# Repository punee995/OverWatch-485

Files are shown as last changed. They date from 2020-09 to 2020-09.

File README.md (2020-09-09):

# OverWatch-485!

Project **OverWatch** initially created for GUVNL R&D Department to Monitor Modbus 3-phase meters over LoRaWAN (IN865). Hardware is developed under KiCAD5. Firmware was written under CoIDE.

## Hardware Specification

 - [x] Universal Input Voltage ( 85VAC - 265VAC )
 - [x] Input surge Voltage protection ( 2000V )
 - [x] Modbus Galvenic Isolation ( 2500V )
 - [x] U.fl Antenna / SMA Antenna / PCB Antenna ( 3dbi* )
 - [x] Protocol : RS422 / RS485 ( 500kbps )
 - [x] Internal Battery / Charger
 - [ ] Reduced Power Consumption

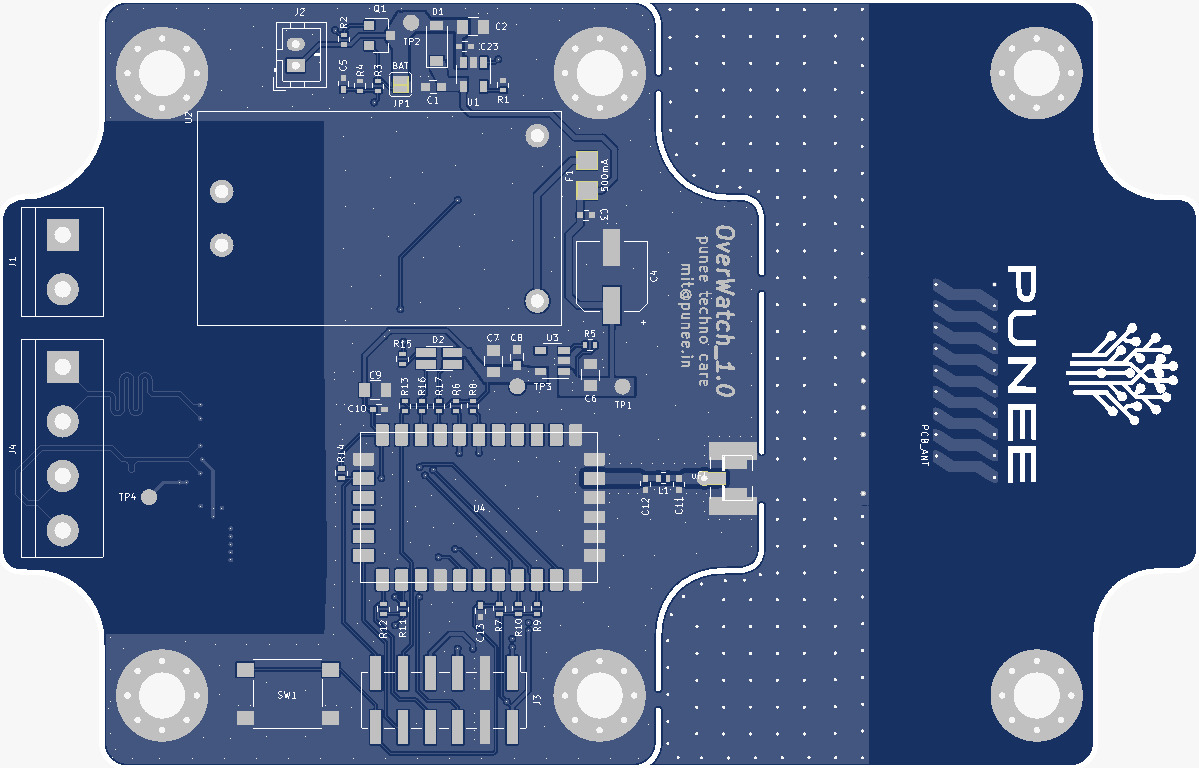
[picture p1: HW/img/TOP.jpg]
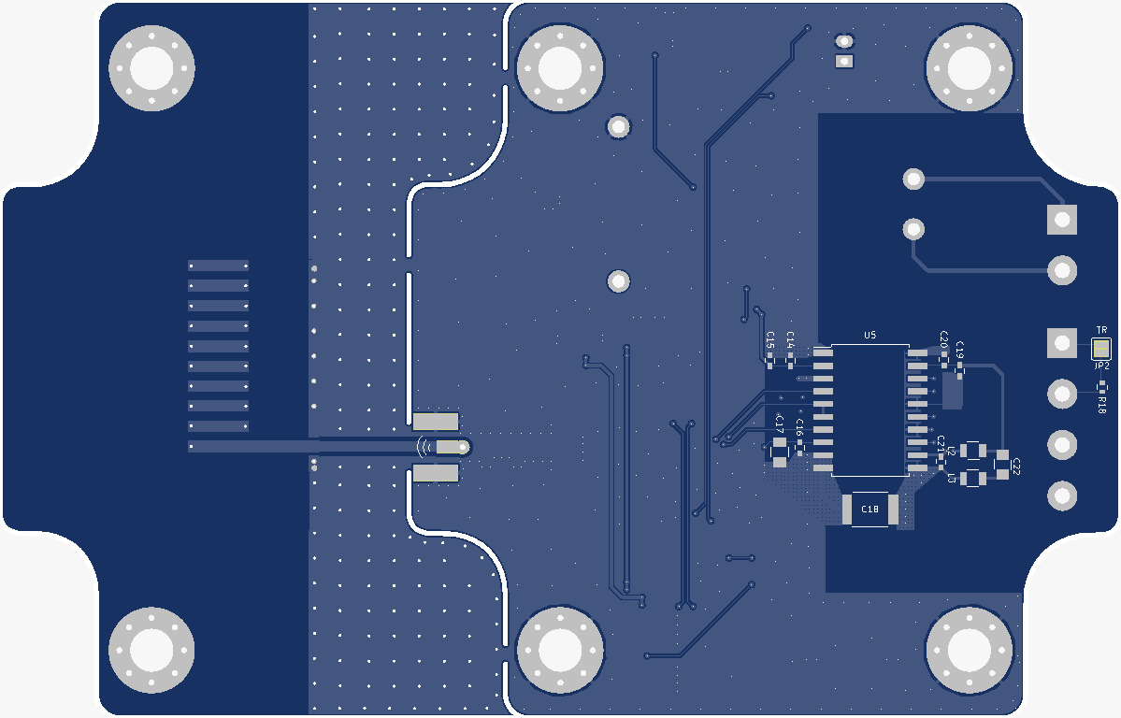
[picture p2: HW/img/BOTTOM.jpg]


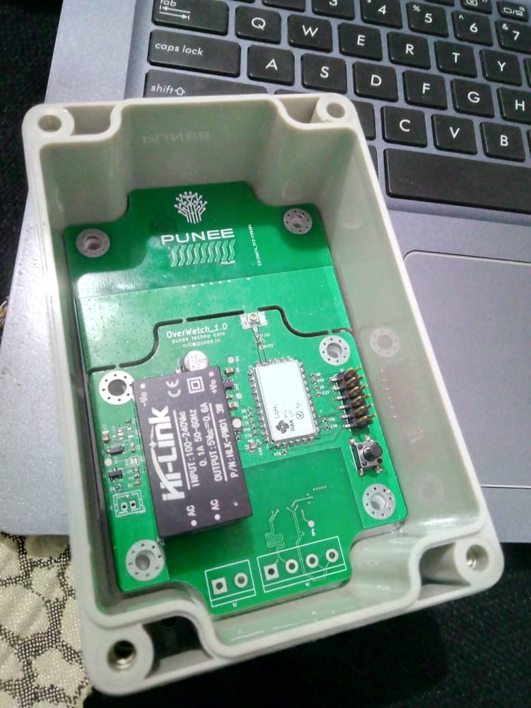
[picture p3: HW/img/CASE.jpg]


## Software Specification
1.  Add the AT command, the command list is shown below;
2.  Modify the time of sending data, and modify it to send a packet of data for 60s;
3.  Integrate all frequency bands, support band switching, and switch frequency bands by AT command;

     AT command list: \
     at+region=EU868/US915/AS923/AU915/IN865/KR920    // Set device region
     
     at+dev_eui=xxxxxxxxxxxxxxxx                      //  Set device dev_eui  \
     at+app_eui=xxxxxxxxxxxxxxxx                      // Set device app_eui  \
     at+app_key=xxxxxxxxxxxxxxxxxxxxxxxxxxxxxxxx      //  Set device app_key 

     at+dev_addr=xxxxxxxx                             // Set device dev_addr \
     at+nwks_key=xxxxxxxxxxxxxxxxxxxxxxxxxxxxxxxx     //  Set device nwks_key  \
     at+apps_key=xxxxxxxxxxxxxxxxxxxxxxxxxxxxxxxx     // Set device apps_key  

     at+join_mode=otaa/abp                            // Set the device to join otaa or abp \

     (Note:Please set the region first, then set the join method.)  \
     After the parameter setting is completed, reset the device enable parameter.

# TODO

## Hardware

 - [ ] Reduce Power Consumption (Currently ~45mA ).
	 - For this Add mosfet to Modbus transreciver.
 - [ ] Add Switch for Device Function as Maseter/Slave.
 - [ ] Protection Devices such as MOV and Fuse(@Mains side).

## Software 

 - [ ] programming of Device over RS485(Modbus).
	 - Settings of LoRaWAN Parameters.
	 - Settings of Modbus Registers.
	 - Settings of Alarm for Alert.

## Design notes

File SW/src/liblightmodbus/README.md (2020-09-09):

# A lightweight, cross-platform Modbus library




<br>[Liblightmodbus on launchpad...](https://launchpad.net/liblightmodbus)

`liblightmodbus` is a very lightweight, highly configurable, platform-independent Modbus RTU library.

## Features
- Minimal resources usage
- Relatively easy to use
- Supports all basic Modbus functions and allows users to define thier own Modbus function handlers
- You can pick specific modules, you want to be included during customized build process
- Supports register/coil access callback functions

*Currently supported functions include: 01, 02, 03, 04, 05, 06, 15, 16 and 22.*
Check out the [online documentation](https://jacajack.github.io/liblightmodbus/) for more technical information and user guide.

If you need help - [email me](mailto:mrjjot@gmail.com). If you want to help - contribute here, on Github. **All contributions are welcome!**

## Platforms on which liblightmodbus is known to run
 - 8-bit AVR (ATmega 8, ATmega 328, etc.)
 - STM32 ARM (STM32F103, STM32L151, etc.)
 - Raspberry Pi
 - i386, amd64
 - PowerPC

## PPA
On Ubuntu/Debian `liblightmodbus` can be obtained from [PPA](https://code.launchpad.net/~mrjjot/+archive/ubuntu/liblightmodbus) (Personal Package Archive).

This is how to install it:
 - Add PPA to your system - `sudo add-apt-repository ppa:mrjjot/liblightmodbus`
 - Update software lists - `sudo apt-get update`
 - Install development package - `sudo apt-get install liblightmodbus-dev`

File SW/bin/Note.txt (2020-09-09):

------------------------------------------------------
*****************************************************
------------------------------------------------------
软件版本V1.1.3 / Software version V1.1.3
更新记录： / Update record:
1.添加支持AT命令，命令列表下表所示； / 1. Add the AT command, the command list is shown below;
2.修改发送数据时间，修改为60s发送一包数据； / 2. Modify the time of sending data, and modify it to send a packet of data for 60s;
3.整合所有频段，支持频段切换，通过AT命令切换频段。 / 3. Integrate all frequency bands, support band switching, and switch frequency bands by AT command;

AT命令列表: / AT command list:

at+region=EU868/US915/AS923/AU915/IN865/KR920    // 设置设备地区频段 / Set device region

at+dev_eui=xxxxxxxxxxxxxxxx                      // 设置设备dev_eui / Set device dev_eui
at+app_eui=xxxxxxxxxxxxxxxx                      // 设置设备app_eui / Set device app_eui
at+app_key=xxxxxxxxxxxxxxxxxxxxxxxxxxxxxxxx      // 设置设备app_key / Set device app_key

at+dev_addr=xxxxxxxx                             // 设置设备dev_addr / Set device dev_addr
at+nwks_key=xxxxxxxxxxxxxxxxxxxxxxxxxxxxxxxx     // 设置设备nwks_key / Set device nwks_key
at+apps_key=xxxxxxxxxxxxxxxxxxxxxxxxxxxxxxxx     // 设置设备apps_key / Set device apps_key

at+join_mode=otaa/abp                            // 设置设备加入方式 otaa 或者 abp / Set the device to join otaa or abp

(Note:Please set the region first, then set the join method.)
参数设置完成后，复位设备启用参数。 / After the parameter setting is completed, reset the device enable parameter.

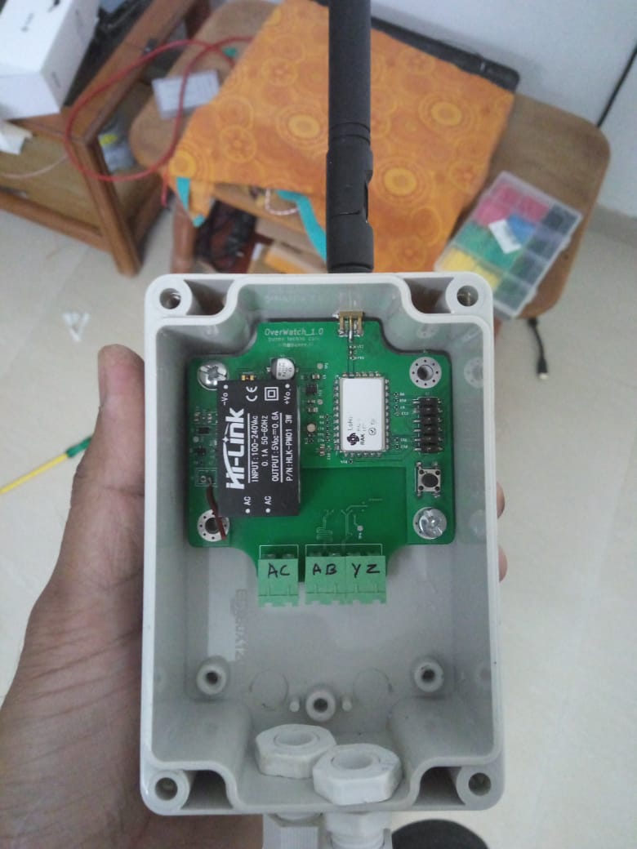
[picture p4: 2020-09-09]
HW/img/EXT_ANT.jpg

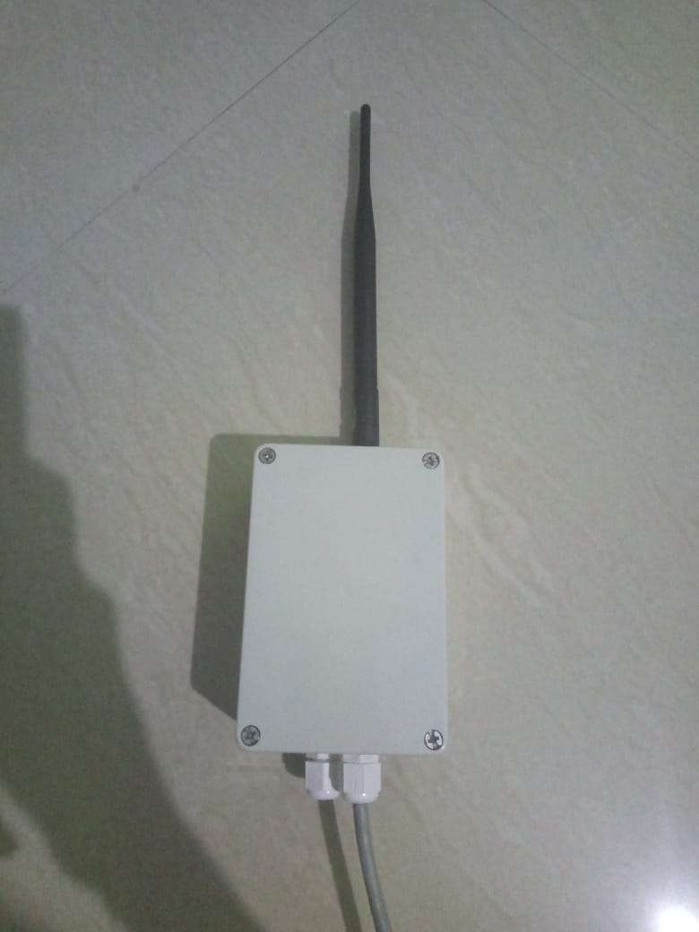
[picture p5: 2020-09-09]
HW/img/index3.jpg

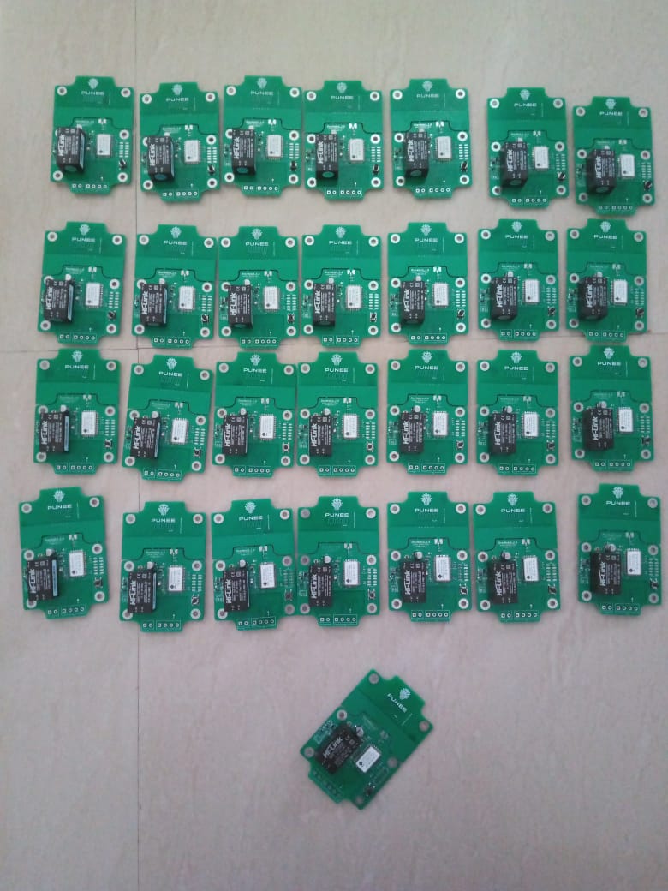
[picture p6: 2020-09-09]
HW/img/FIRST30.jpg

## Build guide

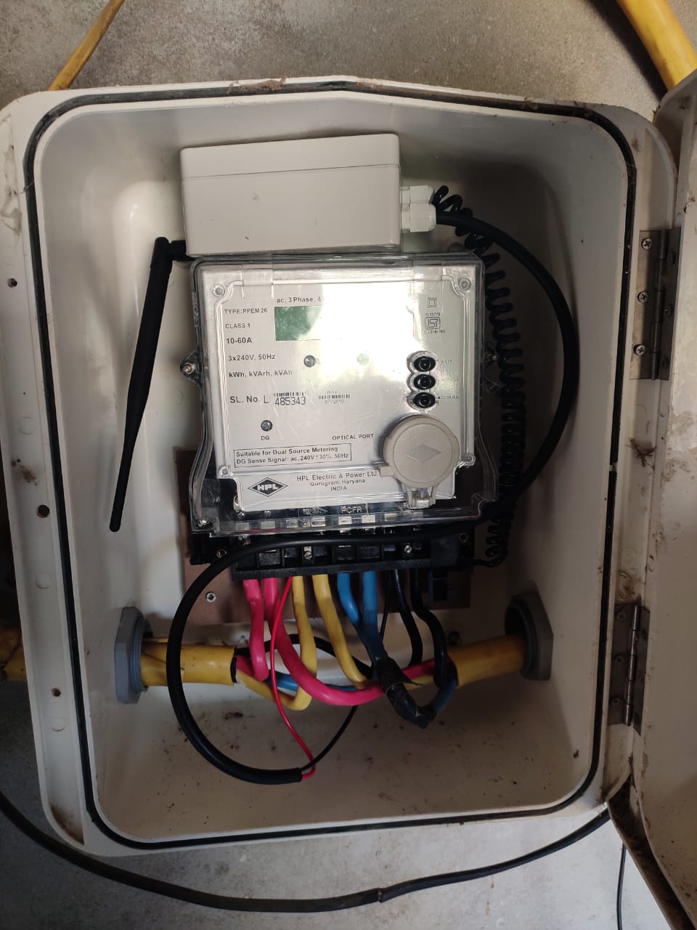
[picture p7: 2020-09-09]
HW/img/INSTALLATION.jpg

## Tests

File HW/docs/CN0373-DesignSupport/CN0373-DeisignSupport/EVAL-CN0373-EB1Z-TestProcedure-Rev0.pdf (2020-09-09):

## CN-0167/CN-0373 Evaluation Board Test Procedure

TEST SET-UP AND EQUIPMENT
Table 1 contains a list of equipment required for this test procedure. Set up and connect the equipment as directed and shown in Figure 1. All connection points and jumper location names refer to the labels on the CN-0167/CN-0373 evaluation board.
Description | Quantity
Adjustable Power Supply (+6 V) | 1
Oscilloscope and 3 probes | 1
Multimeter | 1
Laptop with Tera Term Emulator | 1
USB cable | 1

Procedure:
1. Apply 6 V to the J1 Barrel socket connector to power the board.
2. Connect a USB cable from the Laptop/PC to the J4 connector
3. Install the Tera Term Emulator on the PC/Laptop if required
4. Open a Tera Term emulator window.
a. Select COM5 for RS-232 transmission. Set the Tera Term Serial Port baud rate to 460800.
b. Select COM6 for RS-485 transmission. Set the Tera Term Serial Port baud rate to 460800.
5. Connect the oscilloscope probes to the ISOTXD, Y, and Z test points.

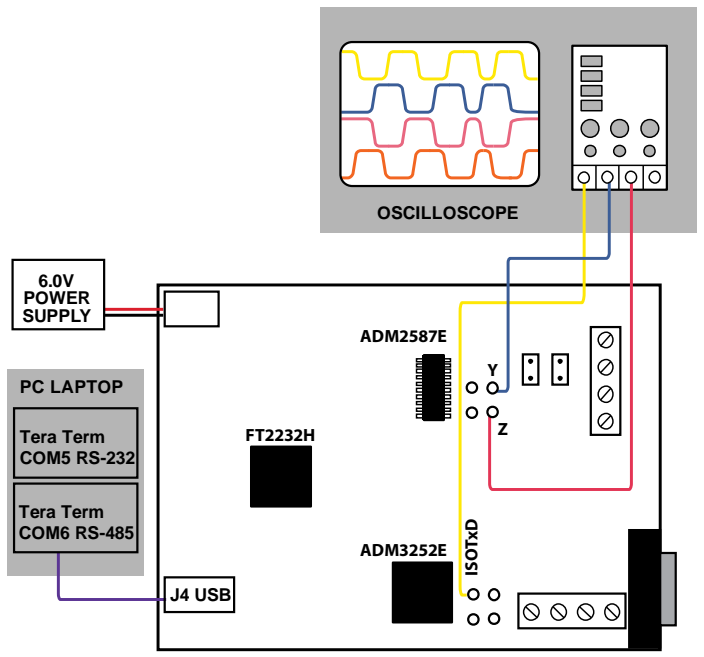
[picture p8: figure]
OSCILLOSCOPE; 6.0V POWER SUPPLY; Tera Term COM6 RS-485; J4 USB; ADM2587E; ADM3252E; OTxD; Z Tera Term COM5 RS-232; PC LAPTOP

Figure 1, Test Setup and Equipment

## CN-0167/CN-0373 Evaluation Board Test Procedure

TEST PROCEDURE

Ensure that setup steps 1 – 5 have been completed. Then perform the initial voltage checks on the test points listed.

INITIAL VOLTAGE CHECK
Measurement Description | Test Point(s) | Typical | Upper Limit | Lower Limit
Measure Input Voltage to the board with the multimeter between barrel connector C1 capacitor and GND1 | C1 capacitor and GND1 | 6.0 V
Measure Input Voltage to the board with the multimeter between U6 pin1 and GND1 | U6 pin1 and GND1 | 5.0 V
Measure voltage on the board with the multimeter between: VCC_REG and GND1_1 | VCC_REG and GND1_1 | 4.99 V
Measure voltage on the board with the multimeter between: ISO_VCC and GND1 | ISO_VCC and GND1 | 3.3 V
Measure voltage on the board with the multimeter between: +1_8V and GND1 | +1_8V and GND1 | 1.8 V
Measure voltage on the board with the multimeter between: VCC and GND3 | VCC and GND3 | 3.3 V
Measure voltage on the board with the multimeter between: LK1 position A ,and GND3 | LK1 position A, and GND3 | 3.3 V
Measure voltage on the board with the multimeter between: VCC1 and GND | VCC1 and GND | 3.3 V
Measure voltage on the board with the multimeter between: VISO and ISOGND | VISO and ISOGND | 3.35 V
Measure voltage on the board with the multimeter between: VISO1 and GND4 | VISO1 and GND4 | 3.34 V

TRANSMIT FROM USB PORT TO RS-485/RS-232 PORTS SIMULTANEOUSLY
1. Connect a USB cable from the Laptop/PC to the J4 connector.
2. Attach an oscilloscope probe to the ISOTXD test point next to the ADM3252E transceiver as shown in Figure 1.
a. Ensure that ISOGND is used as the ground connection for the oscilloscope probe.
3. Attach an oscilloscope probe to the Y and Z test points next to the ADM2587E transceiver as shown in Figure 1.
a. Ensure that Jumpers LK5 and LK6 are not connected. Ensure that Jumper LK1 is connected in position A.
b. Ensure that GND4 is used as the ground connection for the oscilloscope probes.
c. Use the MATH function of the oscilloscope to show the Y-Z differential signal.
4. Open a Tera Term emulator window, and select COM5 for RS-232 transmission, as shown in Figure 1. Set the Tera Term Serial Port baud rate to 460800. [Data: 8 bit, Parity: none, Stop: 1 Bit, Flow Control: none]
5. Open a Tera Term emulator window, and select COM6 for RS-485 transmission, as shown in Figure 1. Set the Tera Term Serial Port baud rate to 460800. [Data: 8 bit, Parity: none, Stop: 1 Bit, Flow Control: none]
6. Load the RS-485 and RS-232 data to be transmitted by selecting the Send option under the File menu for both COM5 and COM6. Choose any large data size file for continuous test transmission and hit send.

## CN-0167/CN-0373 Evaluation Board Test Procedure

Compare the RS-232 signal on channel 1 with Figure 2.

ISOTXD and ISOGND test points See Figure 2

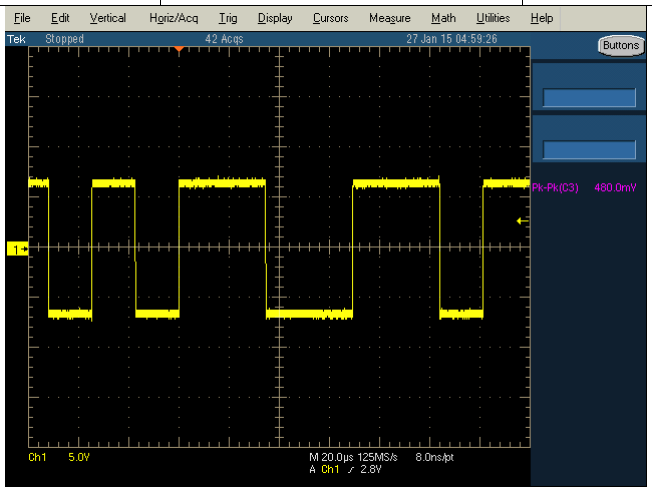
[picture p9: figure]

Figure 2, Isolated RS-232 Measurement - ISOTXD Signal to ISOGND

Compare the RS-485 signal on the MATH with Figure 3. (orange trace)

Y, Z test points, Y-Z MATH signals and GND4 test point

See Figure 3

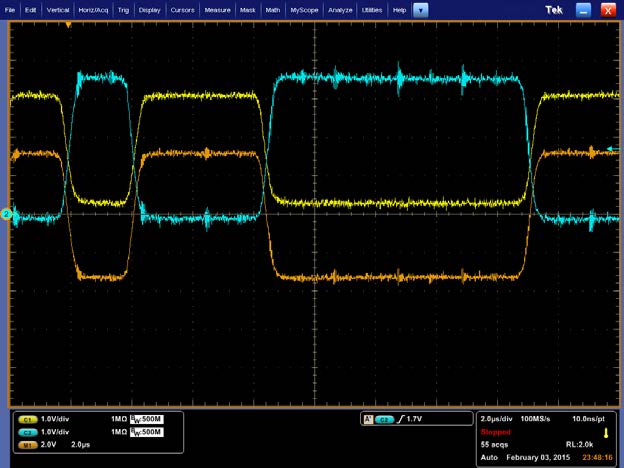
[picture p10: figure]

## CN-0167/CN-0373 Evaluation Board Test Procedure

Figure 3, Isolated RS-485 Measurement - Y-Z MATH Signal to GND Compare the RS-485 signal on the Y and Z pins with Figure 4

Ch1 Yellow = Y
Ch2 Blue = Z
Y, Z test points and GND4 | See Figure 4

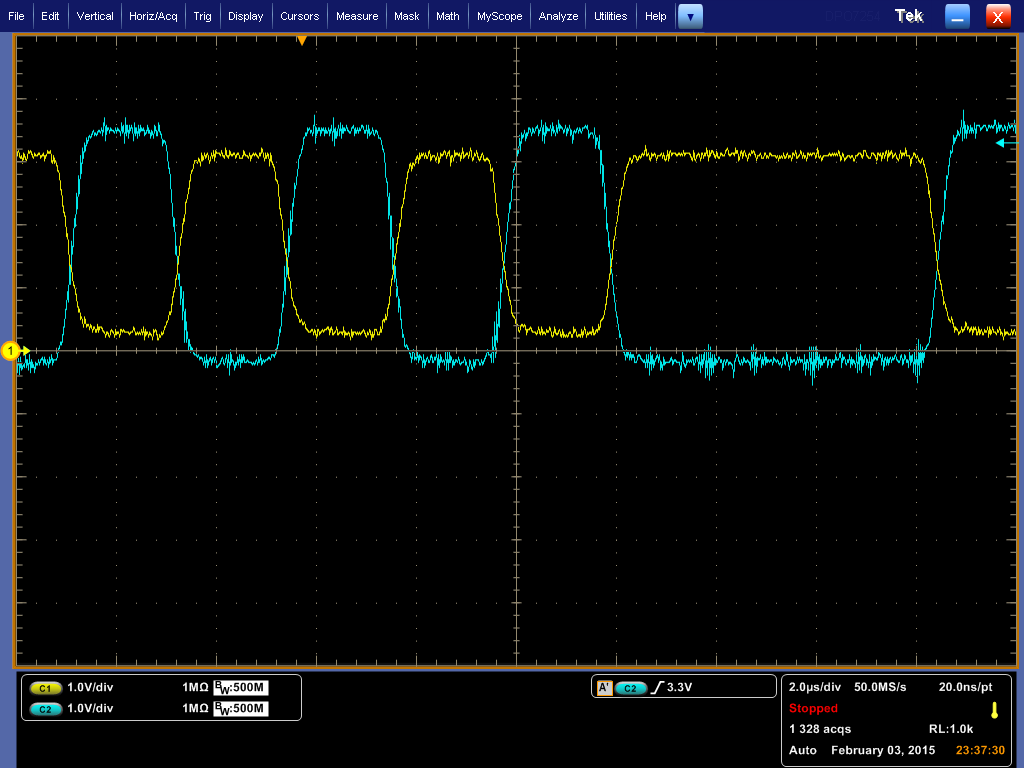
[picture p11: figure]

Figure 4, Isolated RS-485 Measurement – Y and Z Signals to GND4

POST TEST
Disconnect input power from J1, remove USB cable from J4 and remove any additional leads and wires if used.

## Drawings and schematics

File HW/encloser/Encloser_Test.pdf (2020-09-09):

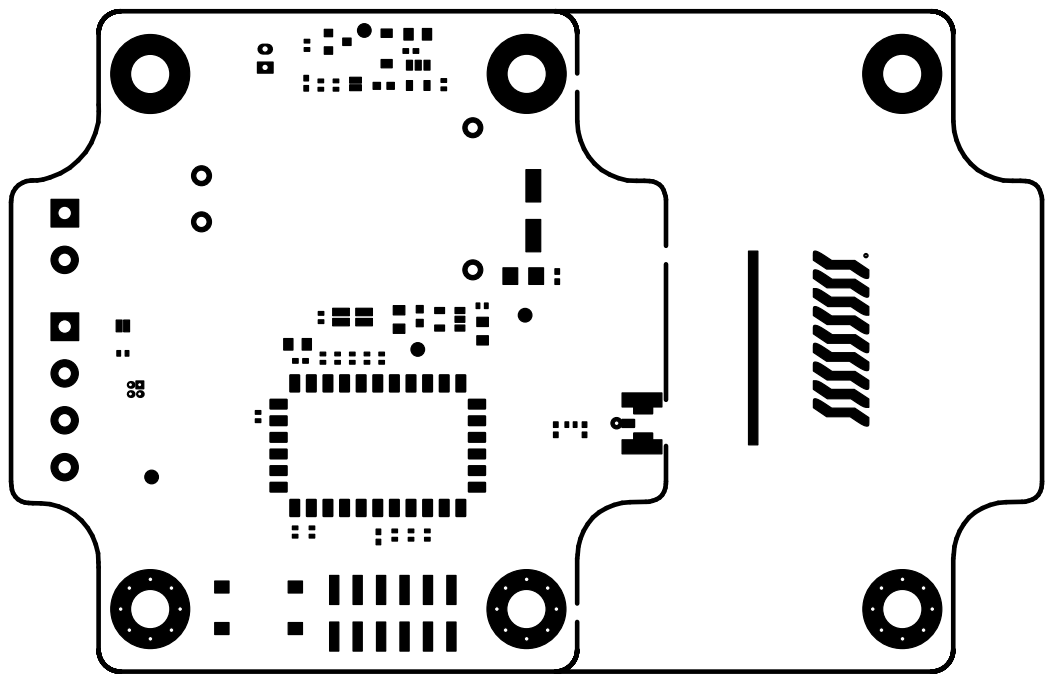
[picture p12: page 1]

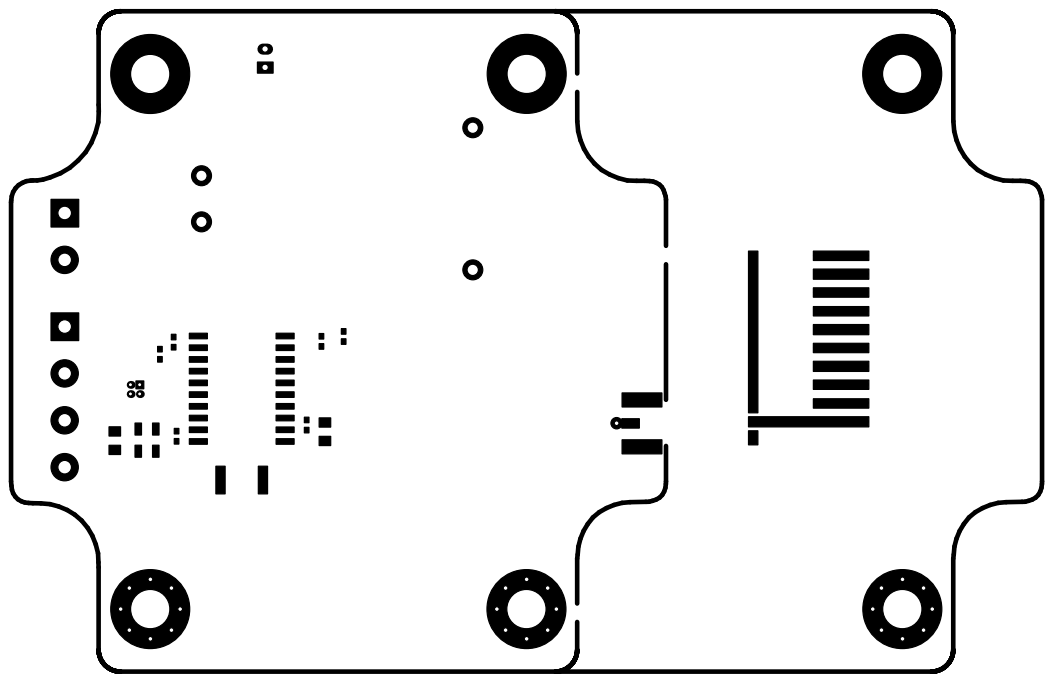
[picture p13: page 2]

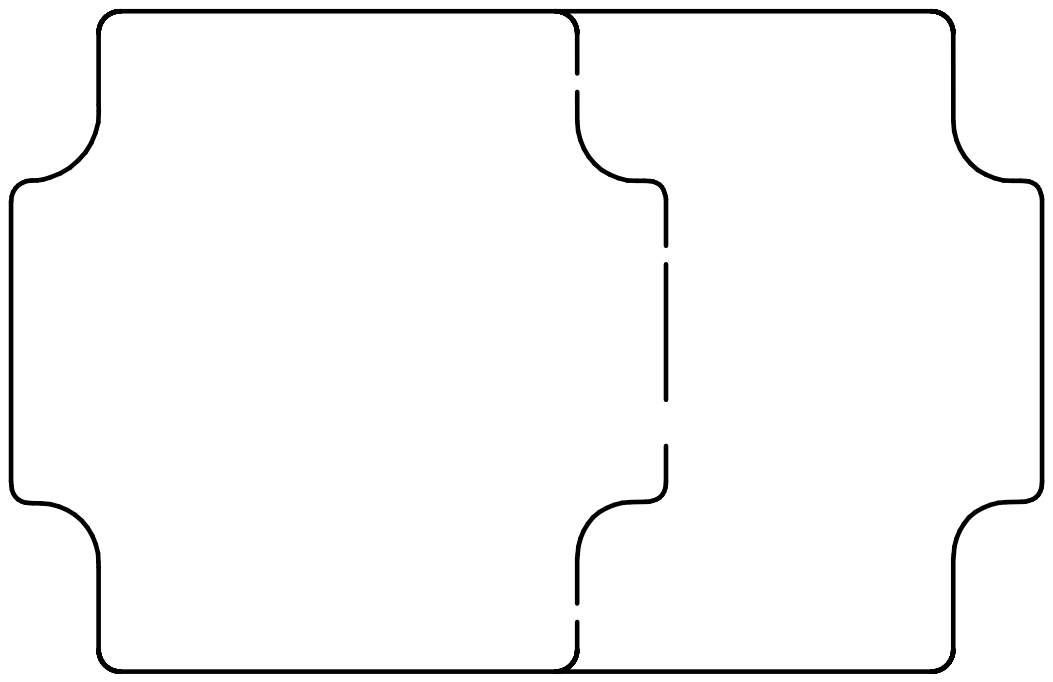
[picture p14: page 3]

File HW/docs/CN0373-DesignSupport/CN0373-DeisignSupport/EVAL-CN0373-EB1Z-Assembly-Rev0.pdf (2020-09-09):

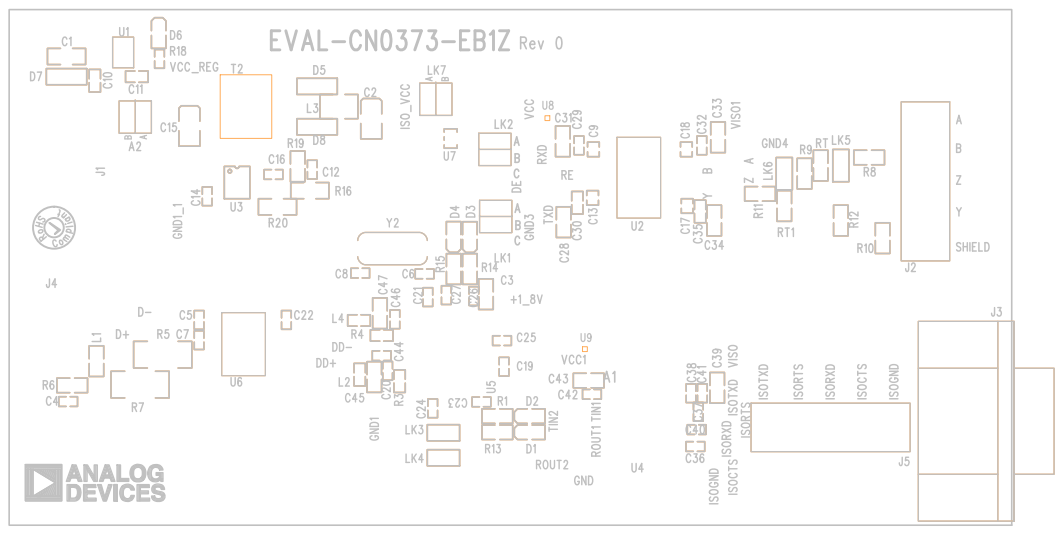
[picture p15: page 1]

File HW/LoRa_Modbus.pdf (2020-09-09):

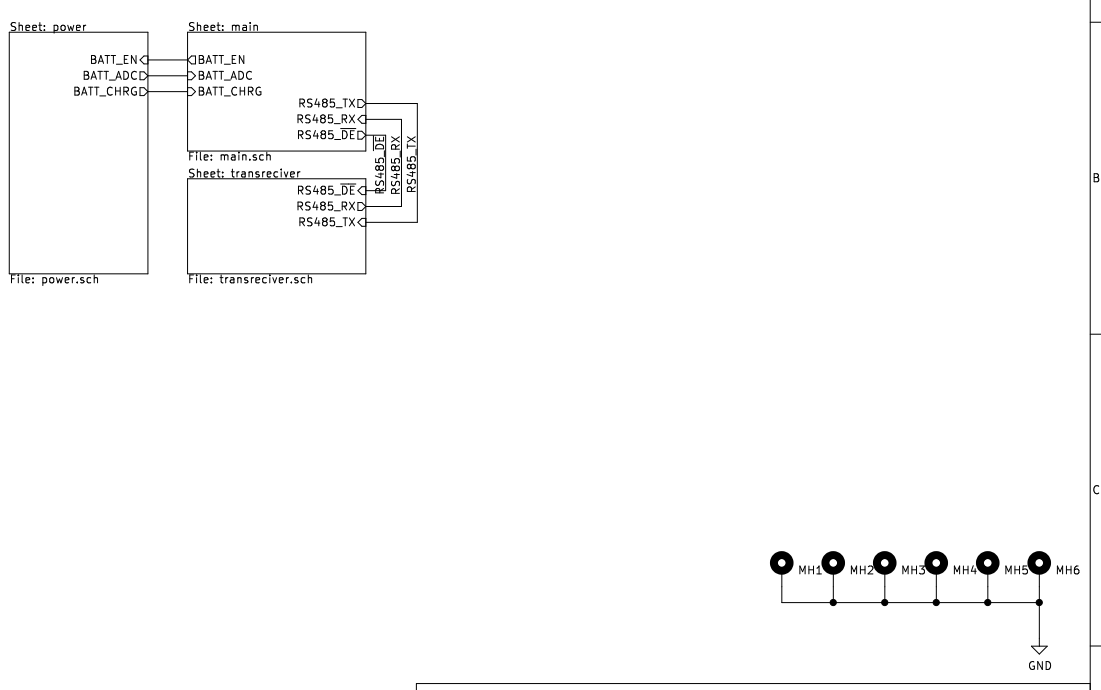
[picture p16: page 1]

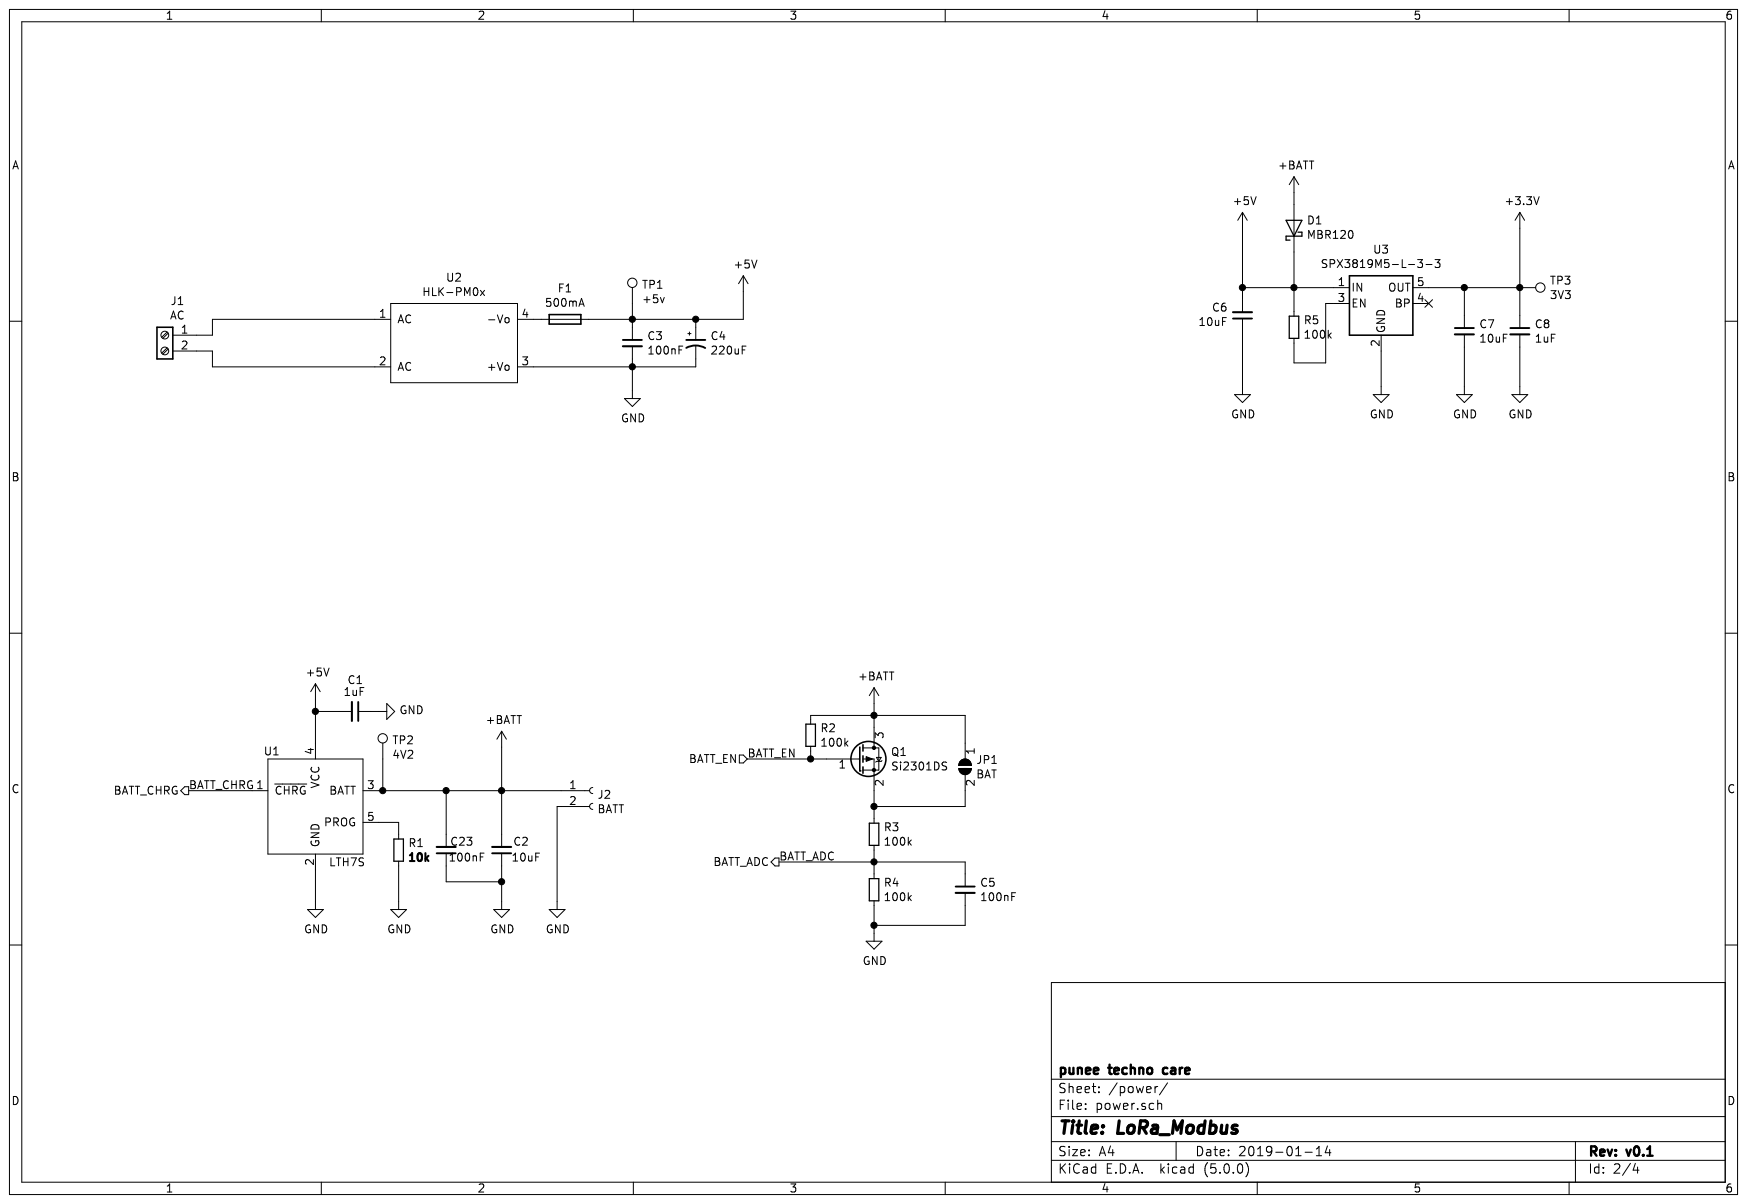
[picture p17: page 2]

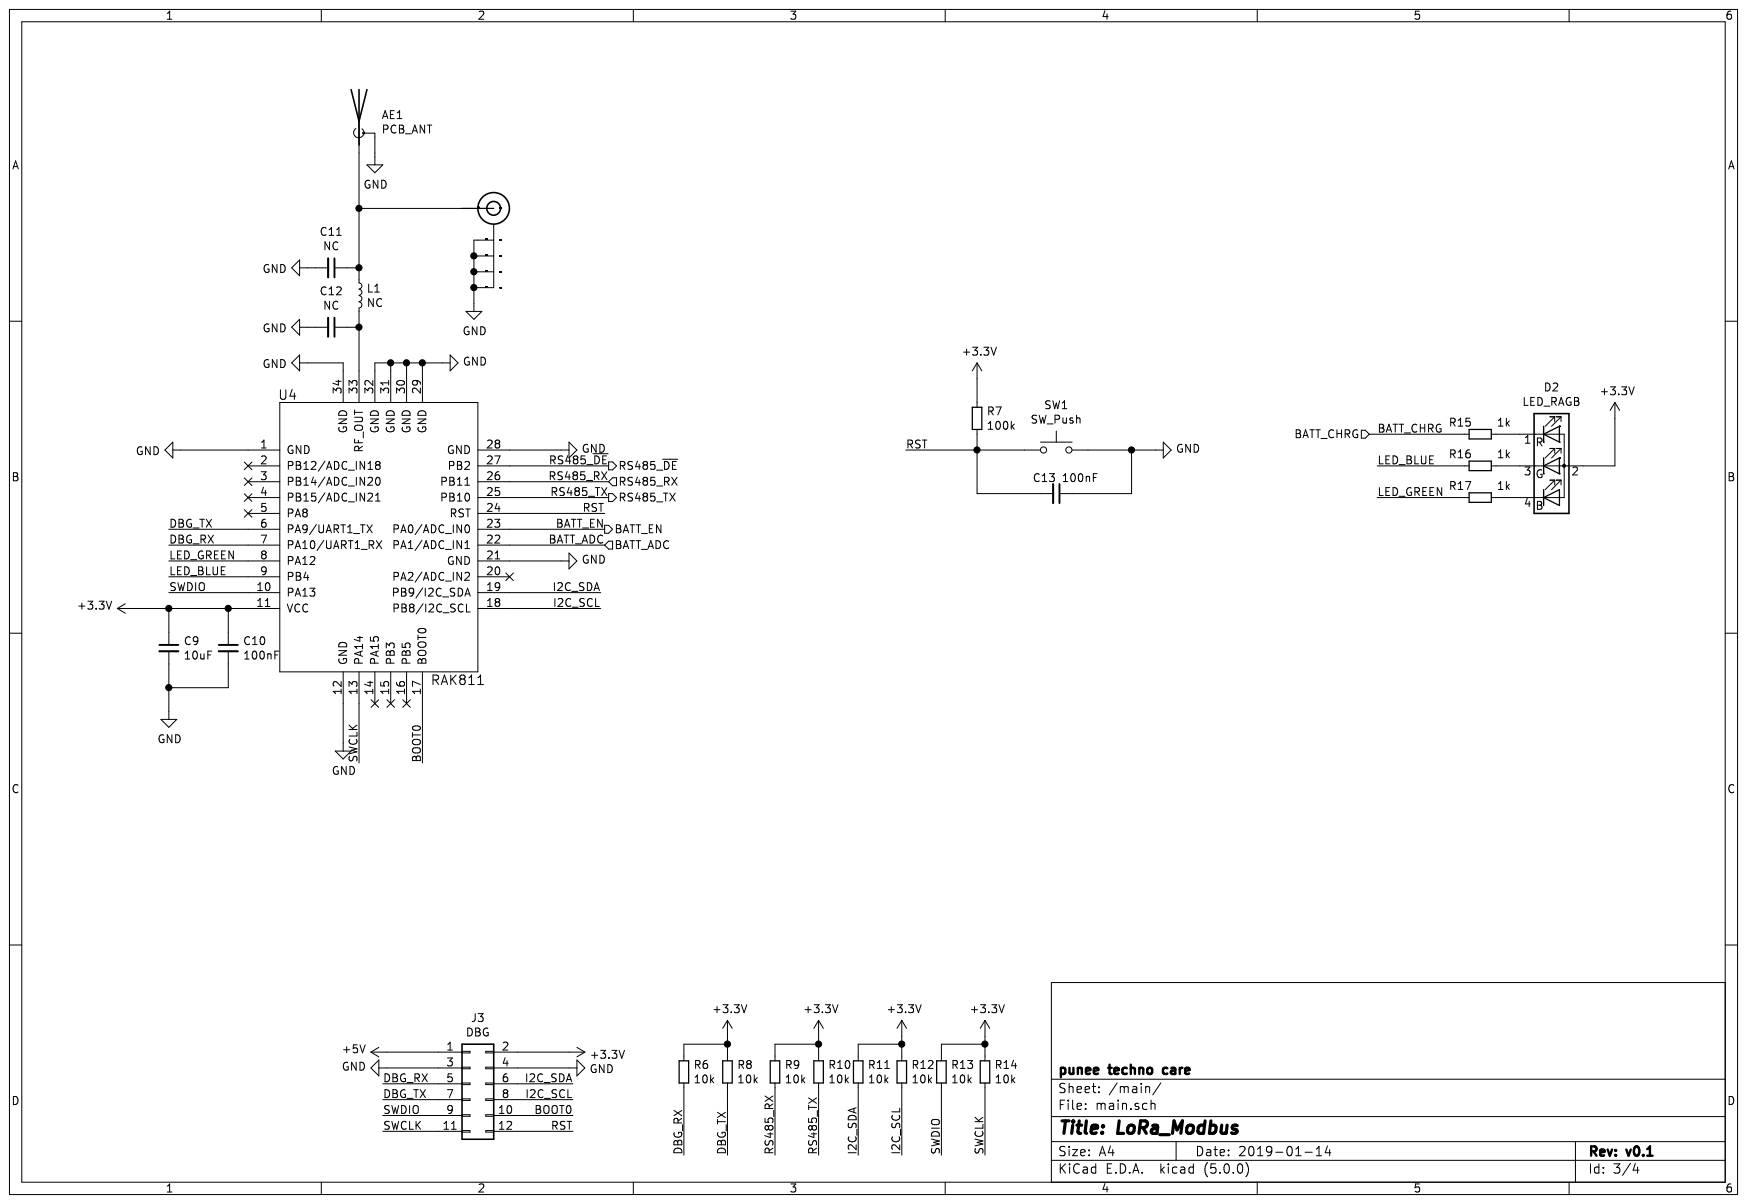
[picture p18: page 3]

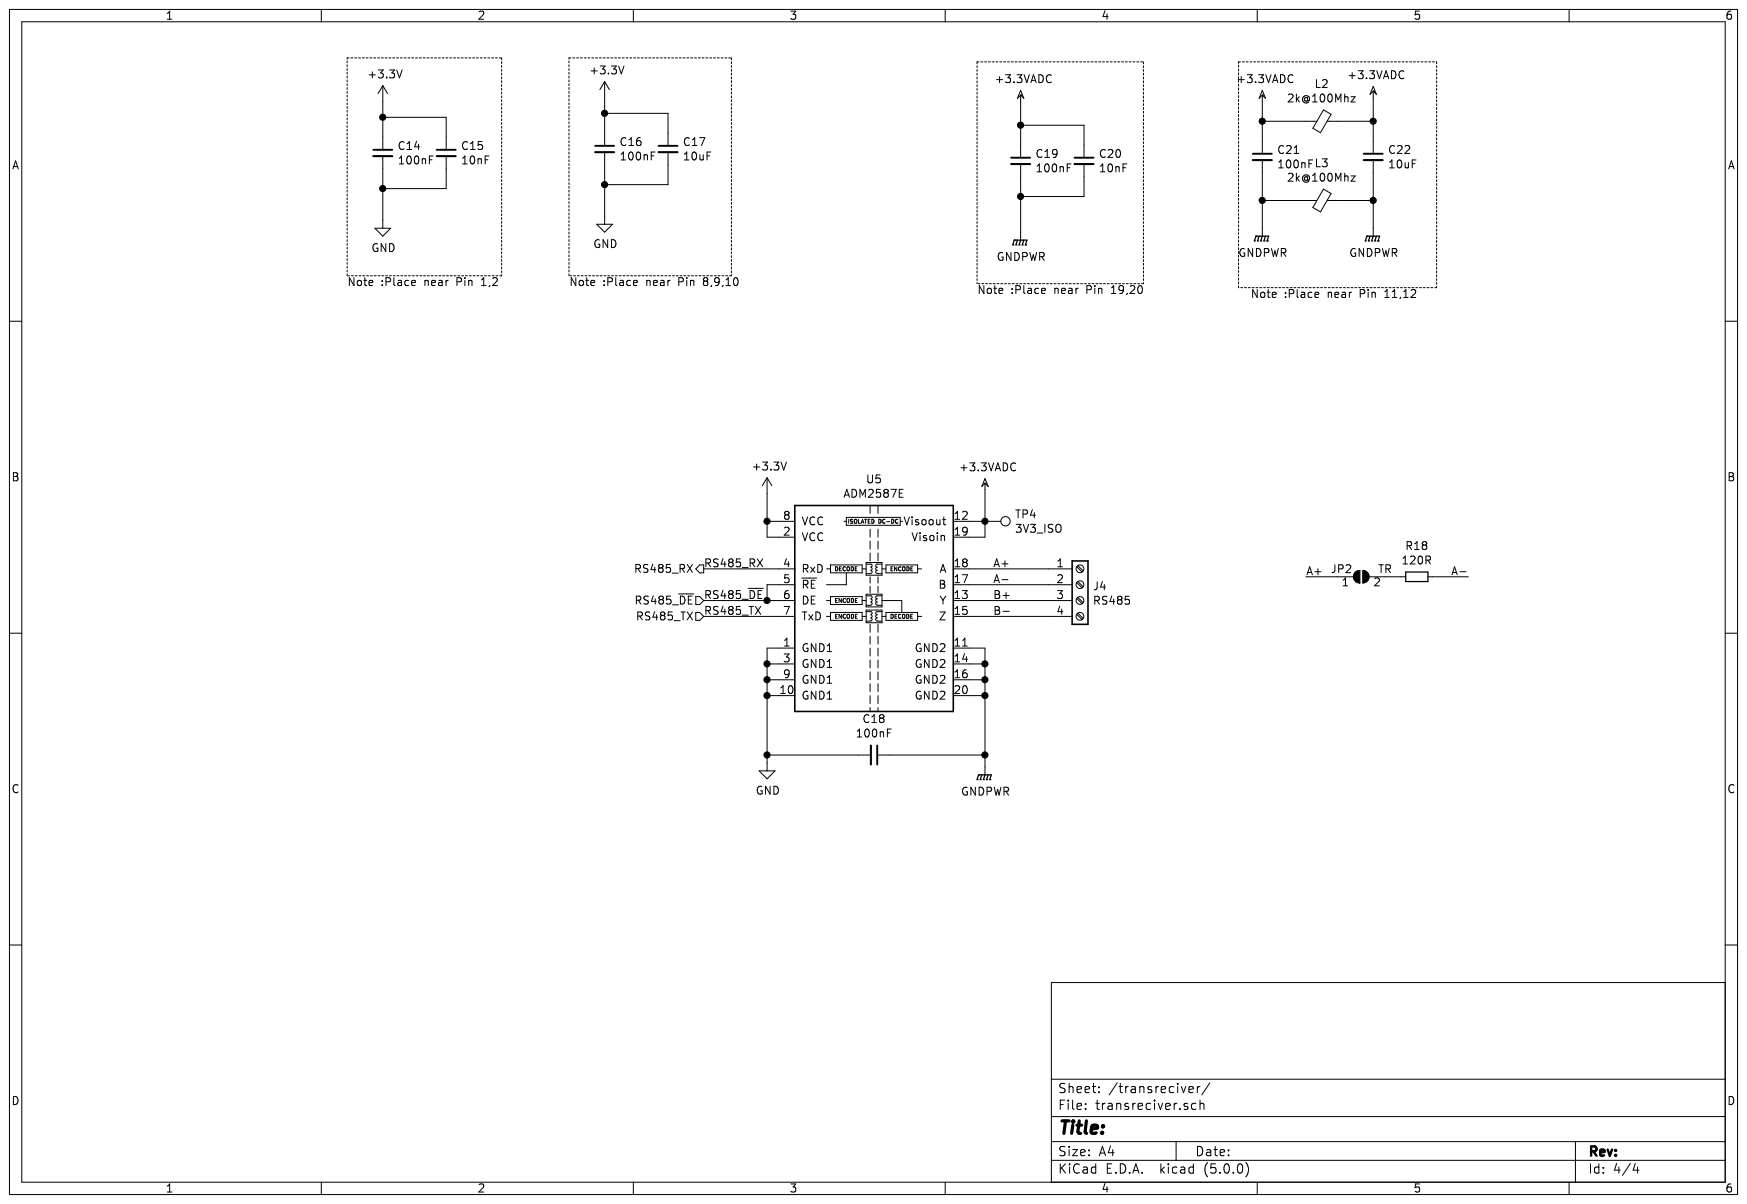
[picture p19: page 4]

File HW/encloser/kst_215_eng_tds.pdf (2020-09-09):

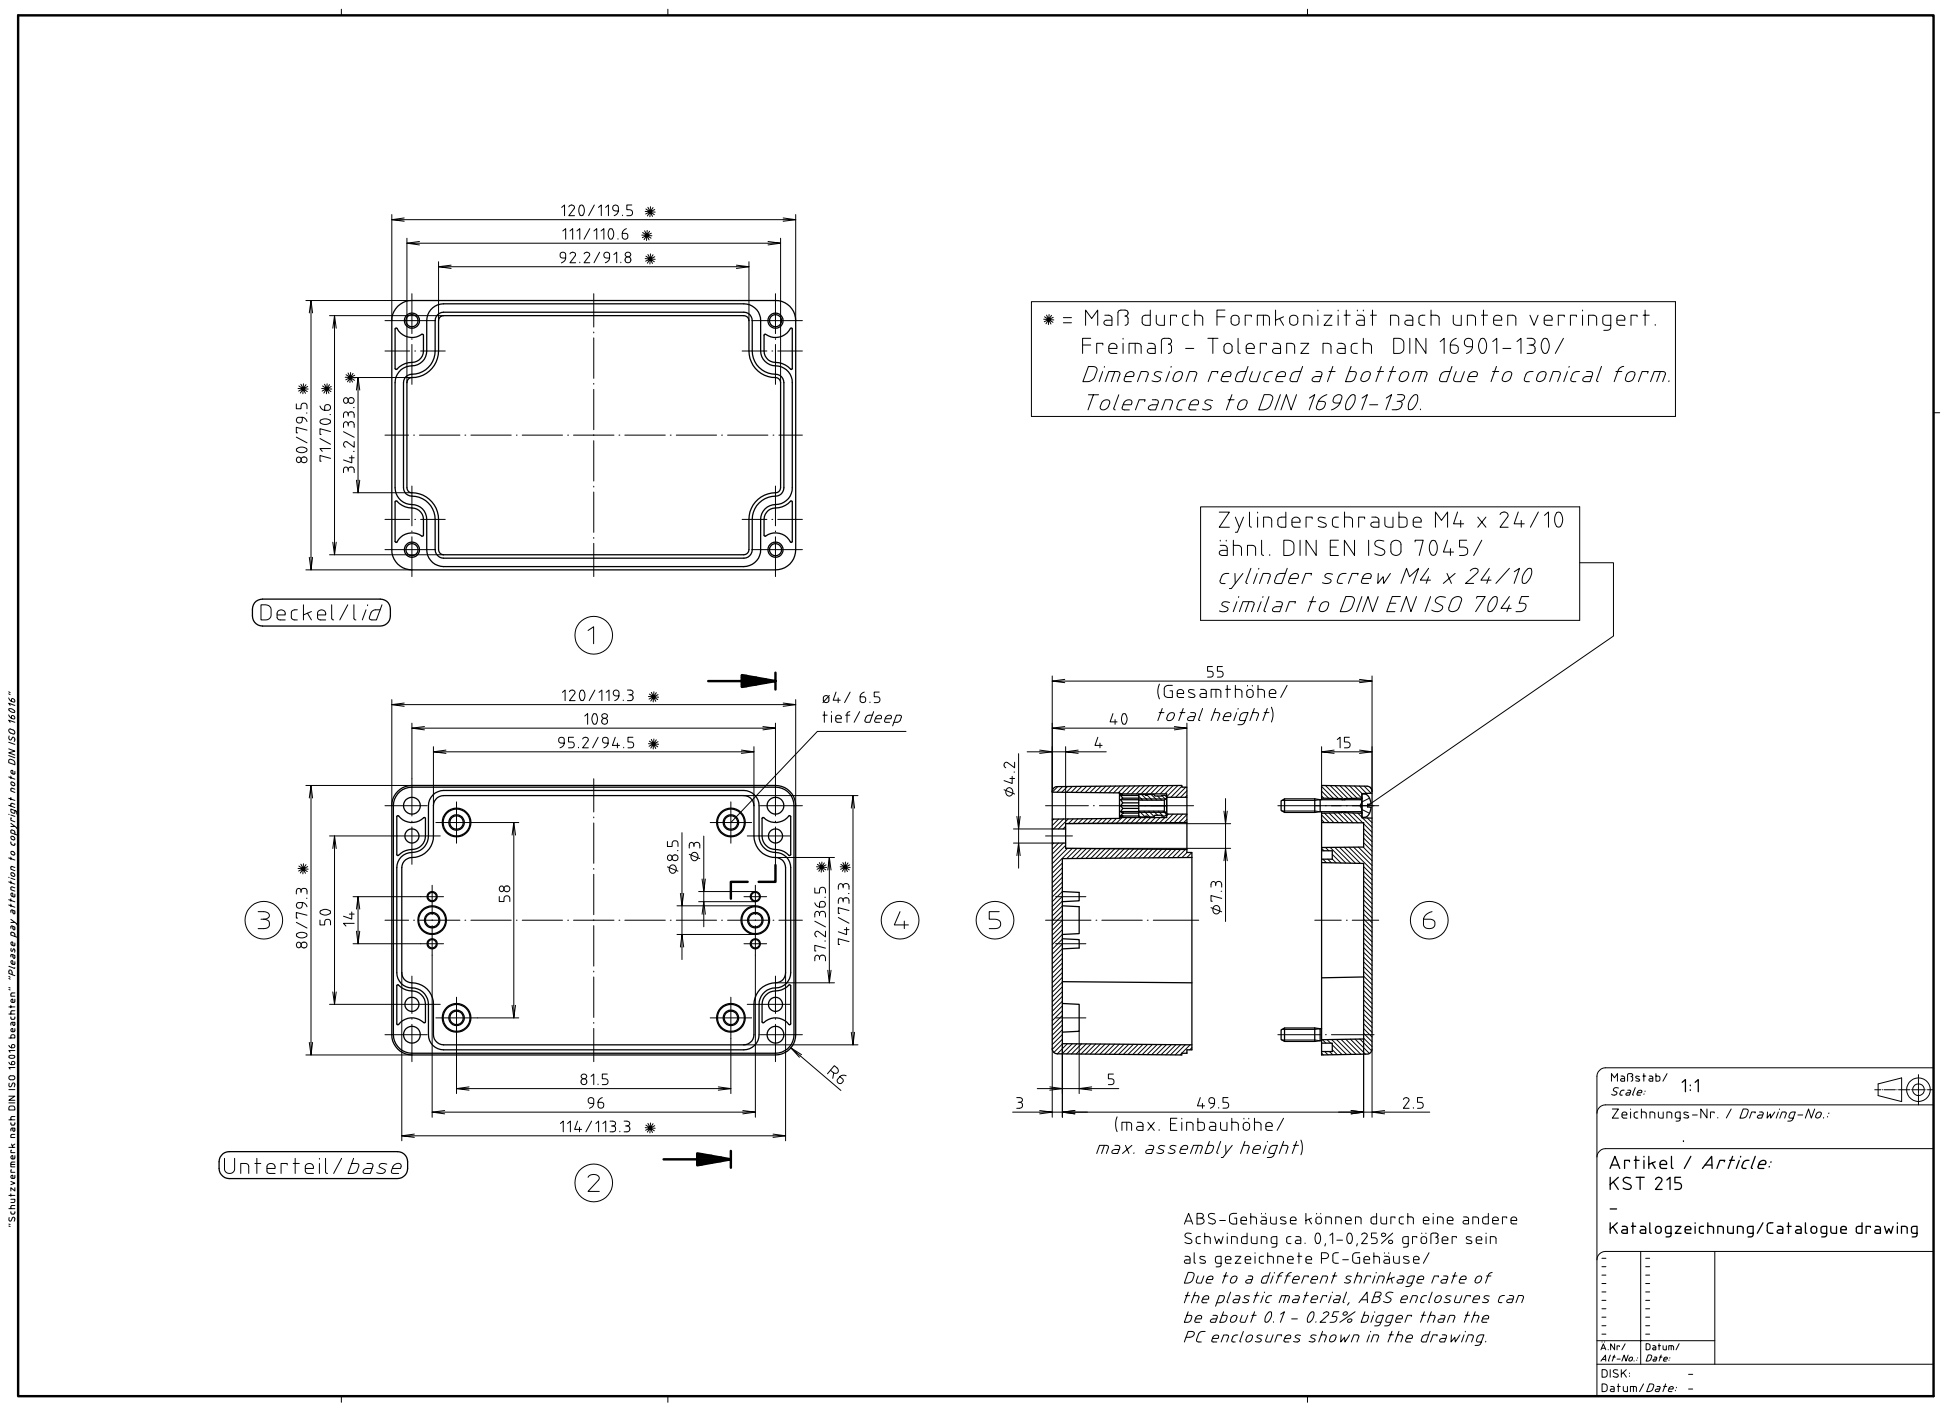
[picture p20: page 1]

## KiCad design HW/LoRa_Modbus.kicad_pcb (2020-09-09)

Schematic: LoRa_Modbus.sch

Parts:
MH1, MH2, MH3, MH4, MH5, MH6: MountingHole_Pad; MountingHole_4.3mm_M4_Pad_Via

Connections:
GND: MH1.1, MH2.1, MH3.1, MH4.1, MH5.1, MH6.1; also elsewhere on the board

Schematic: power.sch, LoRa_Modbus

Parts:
C1, C8: 1uF; C_0603
C2, C6, C7: 10uF; C_0805
C3, C5, C23: 100nF; C_0402
C4: 220uF; CP_Elec_6.3x7.7
D1: MBR120; D_SOD-123
F1: 500mA; 1206
J1: AC; TerminalBlock_bornier-2_P5.08mm
J2: BATT; JST_PH_B2B-PH-K_02x2.00mm_Straight
JP1: BAT; SMT-JUMPER_2_NO_SILK
Q1: Si2301DS; SOT-23
R1: 10k; R_0402
R2, R3, R4, R5: 100k; R_0402
TP1: +5v; Measurement_Point_Round-SMD-Pad_Small
TP2: 4V2; Measurement_Point_Round-SMD-Pad_Small
TP3: 3V3; Measurement_Point_Round-SMD-Pad_Small
U1: LTH7S; SOT-23-5
U2: HLK-PM0x; HLK-PM01
U3: SPX3819M5-L-3-3; SOT-23-5

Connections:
+3V3: C7.1, C8.1, TP3.1, U3.5 (OUT); also elsewhere on the board
+5V: C1.2, C3.1, C4.1, C6.2, D1.1, F1.1, R5.1, TP1.1, U1.4, U3.1 (IN); also elsewhere on the board
+BATT: C2.2, C23.2, D1.2, J2.1, JP1.1, Q1.3, R2.1, TP2.1, U1.3
/main/BATT_ADC: C5.1, R3.2, R4.1; also elsewhere on the board
/main/BATT_CHRG: U1.1; also elsewhere on the board
/main/BATT_EN: Q1.1, R2.2; also elsewhere on the board
GND: C1.1, C2.1, C3.2, C4.2, C5.2, C6.1, C7.2, C8.2, C23.1, J2.2, R1.2, R4.2, U1.2, U2.3, U3.2 (GND); also elsewhere on the board
unnamed: F1.2, U2.4
unnamed: J1.1, U2.1
unnamed: J1.2, U2.2
unnamed: JP1.2, Q1.2, R3.1
unnamed: R1.1, U1.5
unnamed: R5.2, U3.3 (EN)

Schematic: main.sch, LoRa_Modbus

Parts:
AE1: PCB_ANT; SWRA416
C9: 10uF; C_0805
C10, C13: 100nF; C_0402
C11, C12: NC; C_0402
D2: LED_RAGB
J3: DBG; Pin_Header_Straight_2x06_Pitch2.54mm_SMD
J$1: ANTENNATINY; SMA_UFL_PAD_TINY
L1: NC; L_0402
R6, R8, R9, R10, R11, R12, R13, R14: 10k; R_0402
R7: 100k; R_0402
R15, R16, R17: 1k; R_0402
SW1: SW_Push; SW_SPST_PTS645
U4: RAK811; RAK811_MODULE

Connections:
+3V3: C9.1, C10.1, D2.2, J3.2, R6.1, R7.1, R8.1, R9.1, R10.1, R11.1, R12.1, R13.1, R14.1, U4.11; also elsewhere on the board
+5V: J3.1; also elsewhere on the board
/RS485_RX: R9.2, U4.26; also elsewhere on the board
/RS485_TX: R10.2, U4.25; also elsewhere on the board
/RS485_~DE: U4.27; also elsewhere on the board
/main/BATT_ADC: U4.22; also elsewhere on the board
/main/BATT_CHRG: R15.2; also elsewhere on the board
/main/BATT_EN: U4.23; also elsewhere on the board
/main/BOOT0: J3.10, U4.17
/main/DBG_RX: J3.5, R6.2, U4.7
/main/DBG_TX: J3.7, R8.2, U4.6
/main/I2C_SCL: J3.8, R12.2, U4.18
/main/I2C_SDA: J3.6, R11.2, U4.19
/main/LED_BLUE: R16.2, U4.9
/main/LED_GREEN: R17.2, U4.8
/main/RST: C13.2, J3.12, R7.2, SW1.1, U4.24
/main/SWCLK: J3.11, R14.2, U4.13
/main/SWDIO: J3.9, R13.2, U4.10
GND: AE1.2, C9.2, C10.2, C11.2, C12.2, C13.1, J3.3, J3.4, J$1.GND1, J$1.GND2, J$1.GND3, J$1.GND4, SW1.2, U4.1, U4.12, U4.21, U4.28, U4.29, U4.30, U4.31, U4.32, U4.34; also elsewhere on the board
unnamed: AE1.1, C11.1, J$1.ANT1, J$1.ANT2, J$1.ANT3, L1.1
unnamed: C12.1, L1.2, U4.33
unnamed: D2.1, R15.1
unnamed: D2.3, R16.1
unnamed: D2.4, R17.1

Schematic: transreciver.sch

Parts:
C14, C16, C19, C21: 100nF; C_0402
C15, C20: 10nF; C_0402
C17, C22: 10uF; C_0805
C18: 100nF; C_1812
J4: RS485; TerminalBlock_bornier-4_P5.08mm
JP2: TR; SMT-JUMPER_2_NO_SILK
L2, L3: 2k@100Mhz; L_0805
R18: 120R; R_0402
TP4: 3V3_ISO; Measurement_Point_Round-SMD-Pad_Small
U5: ADM2587E; SOIC-20W_7.5x12.8mm_Pitch1.27mm

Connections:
+3.3VADC: C19.1, C20.1, C21.1, C22.1, L2.1, L2.2, TP4.1, U5.12, U5.19
+3V3: C14.1, C15.1, C16.1, C17.1, U5.2, U5.8; also elsewhere on the board
/RS485_RX: U5.4; also elsewhere on the board
/RS485_TX: U5.7; also elsewhere on the board
/RS485_~DE: U5.5, U5.6; also elsewhere on the board
/transreciver/A+: J4.1, JP2.1, U5.18
/transreciver/A-: J4.2, R18.1, U5.17
/transreciver/B+: J4.3, U5.13
/transreciver/B-: J4.4, U5.15
GND: C14.2, C15.2, C16.2, C17.2, C18.2, U5.1, U5.3, U5.9, U5.10; also elsewhere on the board
GNDPWR: C18.1, C19.2, C20.2, C21.2, C22.2, L3.1, L3.2, U5.11, U5.14, U5.16, U5.20
unnamed: JP2.2, R18.2

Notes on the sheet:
Note :Place near Pin 1,2
Note :Place near Pin 8,9,10
Note :Place near Pin 19,20
Note :Place near Pin 11,12

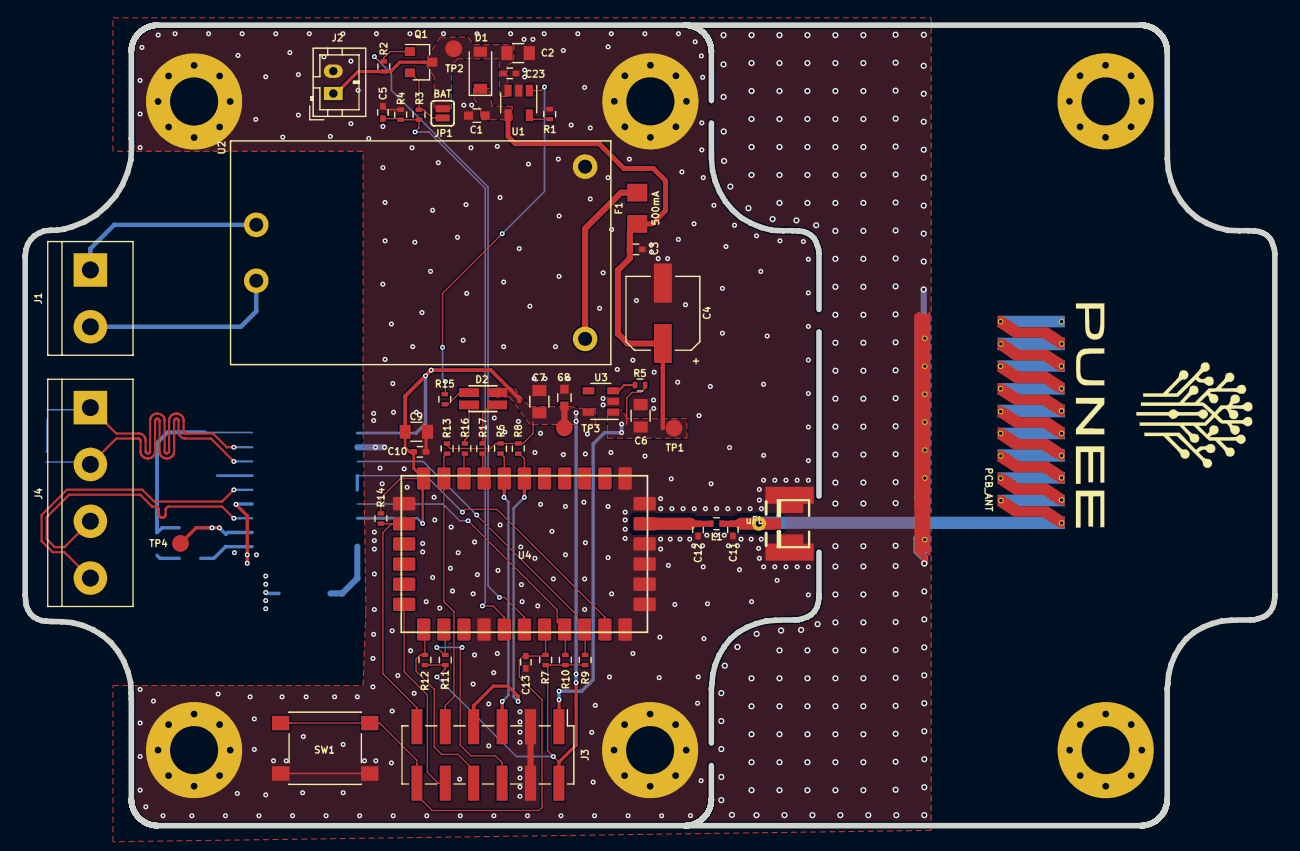
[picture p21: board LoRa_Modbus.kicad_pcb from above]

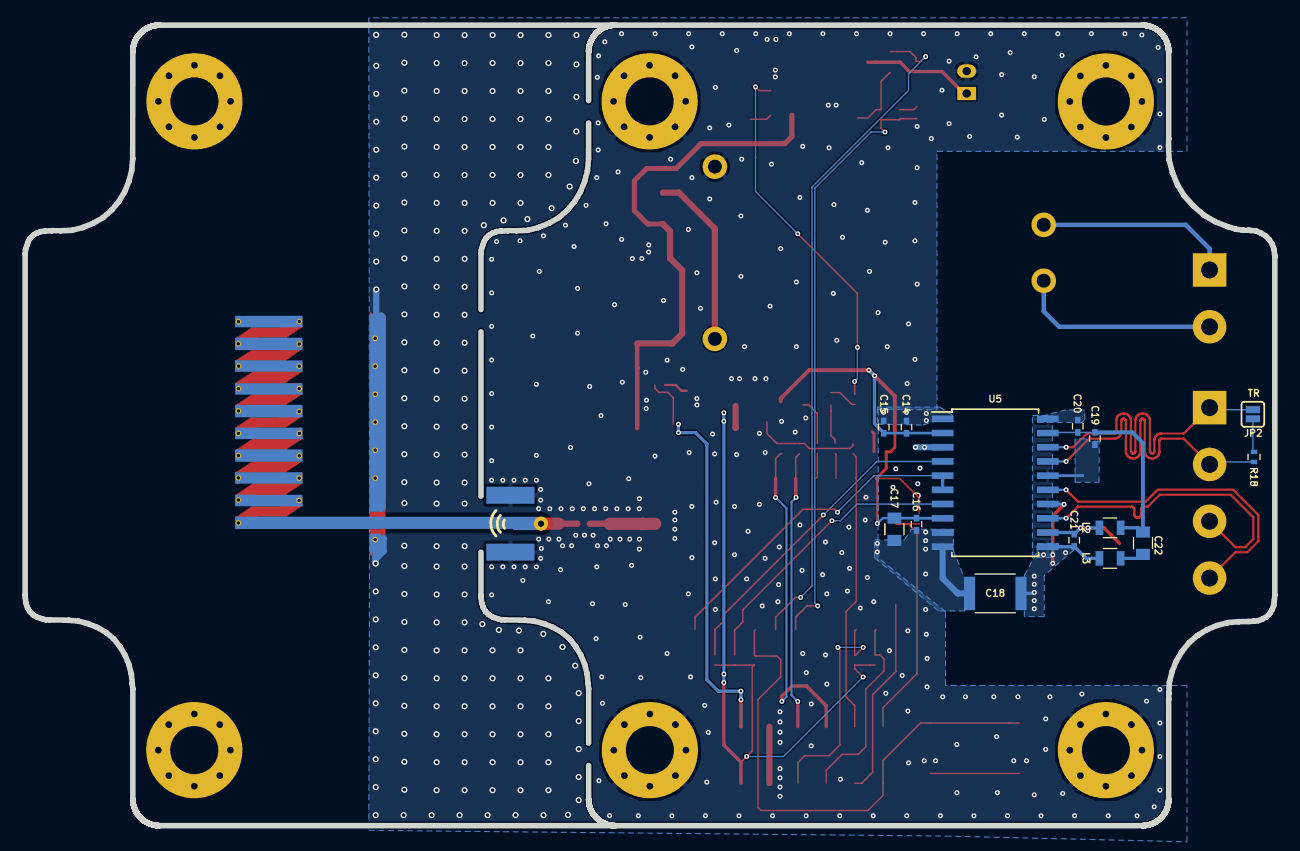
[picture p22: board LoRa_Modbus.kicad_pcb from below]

Board: 2 copper layers, 111.7 x 71.6 mm, 72 parts (15 on the bottom side), 38 nets.

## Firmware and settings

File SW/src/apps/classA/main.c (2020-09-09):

/*
 / _____)             _              | |
 ( (____  _____ ____ _| |_ _____  ____| |__
 \____ \| ___ |    (_   _) ___ |/ ___)  _ \
 _____) ) ____| | | || |_| ____( (___| | | |
 (______/|_____)_|_|_| \__)_____)\____)_| |_|
 (C)2013 Semtech

 Description: LoRaMac classA device implementation

 License: Revised BSD License, see LICENSE.TXT file include in the project

 Maintainer: Miguel Luis and Gregory Cristian
 */

/*! \file classA/SensorNode/main.c */

#include <stdio.h>
#include <string.h>
#include <inttypes.h>
#include <math.h>
#include "board.h"

#include "LoRaMac.h"
#include "Region.h"
#include "Commissioning.h"

#include "lightmodbus.h"
#include "master.h"
#include "slave.h"

uint32_t cnt = 0;
char* rw_Region2Str(LoRaMacRegion_t region);
LoRaMacRegion_t rw_Str2Region(char* region);
LoRaMacRegion_t region;
bool OTAA_JOIN_STATE = false;
#define FLASH_USER_ADDR  0x0801E000
lorawan_config_t g_lorawan_parameter;


/*!
 * Modbus Variable
 */
uint8_t mbData[40*sizeof(int16_t)];

//Configuration structures
ModbusMaster mstatus;

//For storing exit codes
uint8_t mec;

Gpio_t GpsPowerEn;
int mbLen = 0;
bool mbConnect(void);


/*!
 * Defines the application data transmission duty cycle. 5s, value in [ms].
 */
#define APP_TX_DUTYCYCLE                            600000

/*!
 * Defines a random delay for application data transmission duty cycle. 1s,
 * value in [ms].
 */
#define APP_TX_DUTYCYCLE_RND                        1000

/*!
 * Default datarate
 */
#define LORAWAN_DEFAULT_DATARATE                    DR_5

/*!
 * LoRaWAN confirmed messages
 */
#define LORAWAN_CONFIRMED_MSG_ON                    true

/*!
 * LoRaWAN Adaptive Data Rate
 *
 * \remark Please note that when ADR is enabled the end-device should be static
 */
#define LORAWAN_ADR_ON                              1

//#if defined( REGION_EU868 )

#include "LoRaMacTest.h"

/*!
 * LoRaWAN ETSI duty cycle control enable/disable
 *
 * \remark Please note that ETSI mandates duty cycled transmissions. Use only for test purposes
 */
#define LORAWAN_DUTYCYCLE_ON                        false

//#define USE_SEMTECH_DEFAULT_CHANNEL_LINEUP          1

#if( USE_SEMTECH_DEFAULT_CHANNEL_LINEUP == 1 )

#define LC4                { 867100000, 0, { ( ( DR_5 << 4 ) | DR_0 ) }, 0 }
#define LC5                { 867300000, 0, { ( ( DR_5 << 4 ) | DR_0 ) }, 0 }
#define LC6                { 867500000, 0, { ( ( DR_5 << 4 ) | DR_0 ) }, 0 }
#define LC7                { 867700000, 0, { ( ( DR_5 << 4 ) | DR_0 ) }, 0 }
#define LC8                { 867900000, 0, { ( ( DR_5 << 4 ) | DR_0 ) }, 0 }
#define LC9                { 868800000, 0, { ( ( DR_7 << 4 ) | DR_7 ) }, 2 }
#define LC10               { 868300000, 0, { ( ( DR_6 << 4 ) | DR_6 ) }, 1 }

#endif

//#endif

/*!
 * LoRaWAN application port
 */
#define LORAWAN_APP_PORT                            2

/*!
 * User application data buffer size
 */
//#if defined( REGION_CN470 ) || defined( REGION_CN779 ) || defined( REGION_EU433 ) || defined( REGION_EU868 ) || defined( REGION_IN865 ) || defined( REGION_KR920 )

//#define LORAWAN_APP_DATA_SIZE                       16

//#elif defined( REGION_AS923 ) || defined( REGION_AU915 ) || defined( REGION_US915 ) || defined( REGION_US915_HYBRID )

#define LORAWAN_APP_DATA_SIZE                       11

//#else

//#error "Please define a region in the compiler options."

//#endif

//static uint8_t DevEui[] = LORAWAN_DEVICE_EUI;
//static uint8_t AppEui[] = LORAWAN_APPLICATION_EUI;
//static uint8_t AppKey[] = LORAWAN_APPLICATION_KEY;


//static uint8_t NwkSKey[] = LORAWAN_NWKSKEY;
//static uint8_t AppSKey[] = LORAWAN_APPSKEY;

/*!
 * Device address
 */
static uint32_t DevAddr = LORAWAN_DEVICE_ADDRESS;


/*!
 * Application port
 */
static uint8_t AppPort = LORAWAN_APP_PORT;

/*!
 * User application data size
 */
static uint8_t AppDataSize = LORAWAN_APP_DATA_SIZE;

/*!
 * User application data buffer size
 */
#define LORAWAN_APP_DATA_MAX_SIZE                           242

/*!
 * User application data
 */
static uint8_t AppData[LORAWAN_APP_DATA_MAX_SIZE];

/*!
 * Indicates if the node is sending confirmed or unconfirmed messages
 */
static uint8_t IsTxConfirmed = LORAWAN_CONFIRMED_MSG_ON;

/*!
 * Defines the application data transmission duty cycle
 */
static uint32_t TxDutyCycleTime;

/*!
 * Timer to handle the application data transmission duty cycle
 */
static TimerEvent_t TxNextPacketTimer;

/*!
 * Specifies the state of the application LED
 */
static bool AppLedStateOn = false;

/*!
 * Timer to handle the state of LED1
 */
static TimerEvent_t Led1Timer;

/*!
 * Timer to handle the state of LED2
 */
static TimerEvent_t Led2Timer;

/*!
 * Indicates if a new packet can be sent
 */
static bool NextTx = true;

/*!
 * Device states
 */
static enum eDeviceState {
	DEVICE_STATE_INIT,
	DEVICE_STATE_JOIN,
	DEVICE_STATE_SEND,
	DEVICE_STATE_CYCLE,
	DEVICE_STATE_SLEEP
} DeviceState;

/*!
 * LoRaWAN compliance tests support data
 */
struct ComplianceTest_s {
	bool Running;
	uint8_t State;
	bool IsTxConfirmed;
	uint8_t AppPort;
	uint8_t AppDataSize;
	uint8_t *AppDataBuffer;
	uint16_t DownLinkCounter;
	bool LinkCheck;
	uint8_t DemodMargin;
	uint8_t NbGateways;
} ComplianceTest;


//IWDG_HandleTypeDef hiwdg;
//static void MX_IWDG_Init(void)
//{
//  hiwdg.Instance = IWDG;
//  hiwdg.Init.Prescaler = IWDG_PRESCALER_256;
//  hiwdg.Init.Reload = 1250;
//  if (HAL_IWDG_Init(&hiwdg) != HAL_OK)
//  {
//
//  }
//
//}



void dump_hex2str(uint8_t *buf, uint8_t len) {
	for (uint8_t i = 0; i < len; i++) {
		printf("%02X ", buf[i]);
	}
	printf("\r\n");
}

void MbMcuIrqNotify( UartNotifyId_t id )
{
	uint8_t data;
    if( id == UART_NOTIFY_RX )
    {
        if( UartMcuGetChar( &GpsUart, &data ) == 0 )
        {
        	mbData[mbLen] = data;
        	mbLen++;
        }
    }
}

bool mbConnect(void	){
	GpioWrite(&GpsPowerEn, 1);
	DelayMs(20);
//	printf("Sending Data....!\r\n");
	mbLen = 0;
	for (int i = 0; i < mstatus.request.length; i++ ){
		m_printchar(mstatus.request.frame[i]);
		printf("\r\n %d %x" ,i,mstatus.request.frame[i]);
	}
	printf("\r\n");
	GpioWrite(&GpsPowerEn, 0);
	DelayMs(1480);

	// Passing Data of master
	mstatus.response.frame = mbData;
	mstatus.response.length = mbLen;

	mec = modbusParseResponse( &mstatus );
		masterdump();

	if (mec != 0) {
		return false;
		printf("Err Detected");
	}
	return true;
}

//Dump master information
void masterdump( )
{
	int i;
	printf( "\r\n==MASTER DUMP==\r\n" );

	printf( "Received data: slave: %02x, addr: %02x, count: %02x, type: %02x\r\n",
		mstatus.data.address, mstatus.data.index, mstatus.data.count, mstatus.data.type );
	printf( "\t\tvalues:" );
	switch ( mstatus.data.type )
	{
		case MODBUS_HOLDING_REGISTER:
		case MODBUS_INPUT_REGISTER:
			for ( i = 0; i < mstatus.data.count; i++ )
				printf( " %02x", mstatus.data.regs[i] );
			break;

	}
	printf( "\r\n" );

	printf( "Request:" );
	for ( i = 0; i < mstatus.request.length; i++ )
		printf( " %02x", mstatus.request.frame[i] );
	printf( "\r\n" );

	printf( "Response:" );
	for ( i = 0; i < mstatus.response.length; i++ )
		printf( " %02x", mstatus.response.frame[i] );
	printf( "\r\n" );

	printf( "Exit code: %d\r\n", mec );
}


//
///*!
// * \brief   Prepares the payload of the frame
// */
//void test_gps(void) {
//	double latitude, longitude = 0;
//	int16_t altitudeGps = 0xFFFF;
//	uint8_t ret;
//	ret = GpsGetLatestGpsPositionDouble(&latitude, &longitude);
//	altitudeGps = GpsGetLatestGpsAltitude(); // in m
//	//	printf("[Debug]: latitude: %f, longitude: %f , altitudeGps: %d \n", latitude, longitude, altitudeGps);
//}
//
//void test_temp(void) {
//	int8_t tempr = 25;
//
//	LIS3DH_GetTempRaw(&tempr); //only tempr changed value
//	tempr = tempr + 20; // temprature should be calibration  in a right temp for every device
//	printf("[Debug]: tempr: %d Bat: %dmv\r\n", tempr,
//			BoardBatteryMeasureVolage());
//}

uint8_t MODBUS_GETFAIL = FAIL;

static void PrepareTxFrame(uint8_t port) {

	uint8_t ret;
	int i = 0;
	ret = mbConnect();
	switch (port) {
	//https://mydevices.com/cayenne/docs/lora/#lora-cayenne-low-power-payload
	//cayenne LPP GPS
	case 2: {
		if (ret == SUCCESS) {
			for ( i = 0; i < mstatus.response.length; i++ ){
				AppData[i] = mstatus.response.frame[i];
				printf(" %02X",AppData[i]);
			}
			AppDataSize = mstatus.response.length + 1;
			printf("\r\nAppData Size = %s\r\n\r\n",AppDataSize);
		}
		else {
			AppDataSize = 0;
			MODBUS_GETFAIL = SUCCESS;
		}

		}
		break;
		//cayenne LPP Temp
	case 3: {

	}
		break;
		//cayenne LPP Acceleration
	case 4: {

	}
		break;
	case 224:
		if (ComplianceTest.LinkCheck == true) {
			ComplianceTest.LinkCheck = false;
			AppDataSize = 3;
			AppData[0] = 5;
			AppData[1] = ComplianceTest.DemodMargin;
			AppData[2] = ComplianceTest.NbGateways;
			ComplianceTest.State = 1;
		} else {
			switch (ComplianceTest.State) {
			case 4:
				ComplianceTest.State = 1;
				break;
			case 1:
				AppDataSize = 2;
				AppData[0] = ComplianceTest.DownLinkCounter >> 8;
				AppData[1] = ComplianceTest.DownLinkCounter;
				break;
			}
		}
		break;
	default:
		break;
	}
}

/*!
 * \brief   Prepares the payload of the frame
 *
 * \retval  [0: frame could be send, 1: error]
 */
static bool SendFrame(void) {
	McpsReq_t mcpsReq;
	LoRaMacTxInfo_t txInfo;

	if (LoRaMacQueryTxPossible(AppDataSize, &txInfo) != LORAMAC_STATUS_OK) {
		// Send empty frame in order to flush MAC commands
		mcpsReq.Type = MCPS_UNCONFIRMED;
		mcpsReq.Req.Unconfirmed.fBuffer = NULL;
		mcpsReq.Req.Unconfirmed.fBufferSize = 0;
		mcpsReq.Req.Unconfirmed.Datarate = LORAWAN_DEFAULT_DATARATE;
	} else {
		if (IsTxConfirmed == false) {
			mcpsReq.Type = MCPS_UNCONFIRMED;
			mcpsReq.Req.Unconfirmed.fPort = AppPort;
			mcpsReq.Req.Unconfirmed.fBuffer = AppData;
			mcpsReq.Req.Unconfirmed.fBufferSize = AppDataSize;
			mcpsReq.Req.Unconfirmed.Datarate = LORAWAN_DEFAULT_DATARATE;
		} else {
			mcpsReq.Type = MCPS_CONFIRMED;
			mcpsReq.Req.Confirmed.fPort = AppPort;
			mcpsReq.Req.Confirmed.fBuffer = AppData;
			mcpsReq.Req.Confirmed.fBufferSize = AppDataSize;
			mcpsReq.Req.Confirmed.NbTrials = 8;
			mcpsReq.Req.Confirmed.Datarate = LORAWAN_DEFAULT_DATARATE;
		}
	}

	if (LoRaMacMcpsRequest(&mcpsReq) == LORAMAC_STATUS_OK) {
		return false;
	}
	return true;
}

/*!
 * \brief Function executed on TxNextPacket Timeout event
 */
static void OnTxNextPacketTimerEvent(void) {
	MibRequestConfirm_t mibReq;
	LoRaMacStatus_t status;

	TimerStop(&TxNextPacketTimer);

	mibReq.Type = MIB_NETWORK_JOINED;
	status = LoRaMacMibGetRequestConfirm(&mibReq);

	if (status == LORAMAC_STATUS_OK) {
		if (mibReq.Param.IsNetworkJoined == true) {
			DeviceState = DEVICE_STATE_SEND;
			NextTx = true;
		} else {
			DeviceState = DEVICE_STATE_JOIN;
		}
	}
}

/*!
 * \brief Function executed on Led 1 Timeout event
 */
static void OnLed1TimerEvent(void) {
	TimerStop(&Led1Timer);
	// Toggle LED 1
	GpioToggle(&Led1);
	TimerStart(&Led1Timer);
}

///*!
// * \brief Function executed on Led 2 Timeout event
// */
//static void OnLed2TimerEvent(void) {
//	TimerStop(&Led2Timer);
//	// Switch LED 2 OFF
//	GpioWrite(&Led2, 1);
//}

/*!
 * \brief   MCPS-Confirm event function
 *
 * \param   [IN] mcpsConfirm - Pointer to the confirm structure,
 *               containing confirm attributes.
 */
static void McpsConfirm(McpsConfirm_t *mcpsConfirm) {
	printf("\r\n\tMcpsConfirm\r\n");
	if (mcpsConfirm->Status == LORAMAC_EVENT_INFO_STATUS_OK) {
		switch (mcpsConfirm->McpsRequest) {
		case MCPS_UNCONFIRMED: {
			printf("\r\n\t\ttMcpsConfirm - MCPS_UNCONFIRMED\r\n");
			// Check Datarate
			// Check TxPower
			break;
		}
		case MCPS_CONFIRMED: {
			printf("\r\n\t\ttMcpsConfirm - MCPS_CONFIRMED\r\n");
			// Check Datarate
			// Check TxPower
			// Check AckReceived
			// Check NbTrials
			break;
		}
		case MCPS_PROPRIETARY: {
			break;
		}
		default:
			break;
		}

	}
	NextTx = true;
}

/*!
 * \brief   MCPS-Indication event function
 *
 * \param   [IN] mcpsIndication - Pointer to the indication structure,
 *               containing indication attributes.
 */
static void McpsIndication(McpsIndication_t *mcpsIndication) {
	printf("\r\n\tMcpsIndication\r\n");
	if (mcpsIndication->Status != LORAMAC_EVENT_INFO_STATUS_OK) {
		return;
	}

	switch (mcpsIndication->McpsIndication) {
	case MCPS_UNCONFIRMED: {
		printf("\r\n\t\tMcpsIndication - MCPS_UNCONFIRMED\r\n");
		break;
	}
	case MCPS_CONFIRMED: {
		printf("\r\n\t\tMcpsIndication - MCPS_CONFIRMED\r\n");
		break;
	}
	case MCPS_PROPRIETARY: {
		break;
	}
	case MCPS_MULTICAST: {
		break;
	}
	default:
		break;
	}

	// Check Multicast
	// Check Port
	// Check Datarate
	// Check FramePending
	// Check Buffer
	// Check BufferSize
	// Check Rssi
	// Check Snr
	// Check RxSlot

	if (ComplianceTest.Running == true) {
		ComplianceTest.DownLinkCounter++;
	}

	if (mcpsIndication->RxData == true) {
		switch (mcpsIndication->Port) {
		printf("\r\nRecived Something on Port : %d\r\n",mcpsIndication->Port);
		case 1: // The application LED can be controlled on port 1 or 2
		case 2:
			if (mcpsIndication->BufferSize == 1) {

				AppLedStateOn = mcpsIndication->Buffer[0] & 0x01;
				if(((AppLedStateOn & 0x01) != 0)){

				}
				GpioWrite(&Led2, ((AppLedStateOn & 0x01) != 0) ? 0 : 1);
			}
			break;
		case 224:
			if (ComplianceTest.Running == false) {
				// Check compliance test enable command (i)
				if ((mcpsIndication->BufferSize == 4)
						&& (mcpsIndication->Buffer[0] == 0x01)
						&& (mcpsIndication->Buffer[1] == 0x01)
						&& (mcpsIndication->Buffer[2] == 0x01)
						&& (mcpsIndication->Buffer[3] == 0x01)) {
					IsTxConfirmed = false;
					AppPort = 224;
					AppDataSize = 2;
					ComplianceTest.DownLinkCounter = 0;
					ComplianceTest.LinkCheck = false;
					ComplianceTest.DemodMargin = 0;
					ComplianceTest.NbGateways = 0;
					ComplianceTest.Running = true;
					ComplianceTest.State = 1;

					MibRequestConfirm_t mibReq;
					mibReq.Type = MIB_ADR;
					mibReq.Param.AdrEnable = true;
					LoRaMacMibSetRequestConfirm(&mibReq);
					if (0 == strcmp(rw_Region2Str(region),"EU868"))
					{
						LoRaMacTestSetDutyCycleOn( LORAWAN_DUTYCYCLE_ON );
					}
					GpsStop();
				}
			} else {
				ComplianceTest.State = mcpsIndication->Buffer[0];
				switch (ComplianceTest.State) {
				case 0: // Check compliance test disable command (ii)
					IsTxConfirmed = LORAWAN_CONFIRMED_MSG_ON;
					AppPort = LORAWAN_APP_PORT;
					AppDataSize = LORAWAN_APP_DATA_SIZE;
					ComplianceTest.DownLinkCounter = 0;
					ComplianceTest.Running = false;

					MibRequestConfirm_t mibReq;
					mibReq.Type = MIB_ADR;
					mibReq.Param.AdrEnable = LORAWAN_ADR_ON;
					LoRaMacMibSetRequestConfirm(&mibReq);
					if (0 == strcmp(rw_Region2Str(region),"EU868"))
					{
						LoRaMacTestSetDutyCycleOn( LORAWAN_DUTYCYCLE_ON );
					}
					GpsStart();
					break;
				case 1: // (iii, iv)
					AppDataSize = 2;
					break;
				case 2: // Enable confirmed messages (v)
					IsTxConfirmed = true;
					ComplianceTest.State = 1;
					break;
				case 3: // Disable confirmed messages (vi)
					IsTxConfirmed = false;
					ComplianceTest.State = 1;
					break;
				case 4: // (vii)
					AppDataSize = mcpsIndication->BufferSize;

					AppData[0] = 4;
					for (uint8_t i = 1;
							i < MIN(AppDataSize, LORAWAN_APP_DATA_MAX_SIZE);
							i++) {
						AppData[i] = mcpsIndication->Buffer[i] + 1;
					}
					break;
				case 5: // (viii)
				{
					MlmeReq_t mlmeReq;
					mlmeReq.Type = MLME_LINK_CHECK;
					LoRaMacMlmeRequest(&mlmeReq);
				}
					break;
				case 6: // (ix)
				{
					MlmeReq_t mlmeReq;

					// Disable TestMode and revert back to normal operation
					IsTxConfirmed = LORAWAN_CONFIRMED_MSG_ON;
					AppPort = LORAWAN_APP_PORT;
					AppDataSize = LORAWAN_APP_DATA_SIZE;
					ComplianceTest.DownLinkCounter = 0;
					ComplianceTest.Running = false;

					MibRequestConfirm_t mibReq;
					mibReq.Type = MIB_ADR;
					mibReq.Param.AdrEnable = LORAWAN_ADR_ON;
					LoRaMacMibSetRequestConfirm(&mibReq);
					if (0 == strcmp(rw_Region2Str(region),"EU868"))
					{
						LoRaMacTestSetDutyCycleOn( LORAWAN_DUTYCYCLE_ON );
					}

					GpsStart();

					mlmeReq.Type = MLME_JOIN;

					mlmeReq.Req.Join.DevEui = g_lorawan_parameter.dev_eui;
					mlmeReq.Req.Join.AppEui = g_lorawan_parameter.app_eui;
					mlmeReq.Req.Join.AppKey = g_lorawan_parameter.app_key;
					mlmeReq.Req.Join.NbTrials = 3;

					LoRaMacMlmeRequest(&mlmeReq);
					DeviceState = DEVICE_STATE_SLEEP;
				}
					break;
				case 7: // (x)
				{
					if (mcpsIndication->BufferSize == 3) {
						MlmeReq_t mlmeReq;
						mlmeReq.Type = MLME_TXCW;
						mlmeReq.Req.TxCw.Timeout = (uint16_t)(
								(mcpsIndication->Buffer[1] << 8)
										| mcpsIndication->Buffer[2]);
						LoRaMacMlmeRequest(&mlmeReq);
					} else if (mcpsIndication->BufferSize == 7) {
						MlmeReq_t mlmeReq;
						mlmeReq.Type = MLME_TXCW_1;
						mlmeReq.Req.TxCw.Timeout = (uint16_t)(
								(mcpsIndication->Buffer[1] << 8)
										| mcpsIndication->Buffer[2]);
						mlmeReq.Req.TxCw.Frequency =
								(uint32_t) ((mcpsIndication->Buffer[3] << 16)
										| (mcpsIndication->Buffer[4] << 8)
										| mcpsIndication->Buffer[5]) * 100;
						mlmeReq.Req.TxCw.Power = mcpsIndication->Buffer[6];
						LoRaMacMlmeRequest(&mlmeReq);
					}
					ComplianceTest.State = 1;
				}
					break;
				default:
					break;
				}
			}
			break;
		default:
			break;
		}
	}

	// Switch LED 1 ON for each received downlink
	GpioWrite(&Led1, 0);
	TimerStart(&Led1Timer);
}

/*!
 * \brief   MLME-Confirm event function
 *
 * \param   [IN] mlmeConfirm - Pointer to the confirm structure,
 *               containing confirm attributes.
 */
static void MlmeConfirm(MlmeConfirm_t *mlmeConfirm) {
	printf("\r\n\tMlmeConfirm\r\n");
	switch (mlmeConfirm->MlmeRequest) {
	case MLME_JOIN: {
		if (mlmeConfirm->Status == LORAMAC_EVENT_INFO_STATUS_OK) {
			// Status is OK, node has joined the network
			DeviceState = DEVICE_STATE_SEND;
			printf("OTAA Join Success \r\n");
			// Switch LED 1 ON
			OTAA_JOIN_STATE = true;
			GpioWrite(&Led1, 0);
			TimerStart(&Led1Timer);
		} else {
			// Join was not successful. Try to join again
			DeviceState = DEVICE_STATE_JOIN;
		}
		break;
	}
	case MLME_LINK_CHECK: {
		if (mlmeConfirm->Status == LORAMAC_EVENT_INFO_STATUS_OK) {
			// Check DemodMargin
			// Check NbGateways
			if (ComplianceTest.Running == true) {
				ComplianceTest.LinkCheck = true;
				ComplianceTest.DemodMargin = mlmeConfirm->DemodMargin;
				ComplianceTest.NbGateways = mlmeConfirm->NbGateways;
			}
		}
		break;
	}
	default:
		break;
	}
	NextTx = true;
}

char* rw_Region2Str(LoRaMacRegion_t region)
{
  switch(region) {
    case LORAMAC_REGION_AS923: return "AS923";
    case LORAMAC_REGION_AU915: return "AU915";
    case LORAMAC_REGION_CN470: return "CN470";
    case LORAMAC_REGION_CN779: return "CN779";
    case LORAMAC_REGION_EU433: return "EU433";
    case LORAMAC_REGION_EU868: return "EU868";
    case LORAMAC_REGION_KR920: return "KR920";
    case LORAMAC_REGION_IN865: return "IN865";
    case LORAMAC_REGION_US915: return "US915";
    case LORAMAC_REGION_US915_HYBRID: return "US915_H";
  default:
    return "";
  }
}

LoRaMacRegion_t rw_Str2Region(char* region)
{
  if ( 0==strcmp(region, "AS923")) {
     return LORAMAC_REGION_AS923;
  } else if (0==strcmp(region, "AU915")) {
     return LORAMAC_REGION_AU915;
  }else if (0==strcmp(region, "CN470")) {
     return LORAMAC_REGION_CN470;
  }else if (0==strcmp(region, "CN779")) {
     return LORAMAC_REGION_CN779;
  }else if (0==strcmp(region, "EU433")) {
     return LORAMAC_REGION_EU433;
  }else if (0==strcmp(region, "EU868")) {
     return LORAMAC_REGION_EU868;
  }else if (0==strcmp(region, "KR920")) {
     return LORAMAC_REGION_KR920;
  }else if (0==strcmp(region, "IN865")) {
     return LORAMAC_REGION_IN865;
  }else if (0==strcmp(region, "US915")) {
     return LORAMAC_REGION_US915;
  }else if (0==strcmp(region, "US915_H")) {
     return LORAMAC_REGION_US915_HYBRID;
  }else {
     return -1;
  }
}

LoRaMacPrimitives_t LoRaMacPrimitives;
LoRaMacCallback_t LoRaMacCallbacks;
MibRequestConfirm_t mibReq;
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
int main (void)
{
	BoardInitMcu();
	BoardInitPeriph();

	for(int i=0; i < 2; i++){
		GpioWrite(&Led2,1);
		DelayMs(250);
		GpioWrite(&Led2,0);
		DelayMs(250);
	}

	// Init WatchDogs
//	MX_IWDG_Init();

	GpsUart.IrqNotify = MbMcuIrqNotify;
	UartMcuInit(&GpsUart, UART_3, GPS_UART_TX, GPS_UART_RX);
	UartMcuConfig(&GpsUart, RX_TX, 9600,
								UART_8_BIT,
								UART_1_STOP_BIT,
								NO_PARITY,
								NO_FLOW_CTRL);

//	GpioInit( &GpsPowerEn, GPS_POWER_ON_PIN, PIN_OUTPUT, PIN_PUSH_PULL, PIN_NO_PULL, 0 );
	GpioInit( &GpsPowerEn, REDE_PIN, PIN_OUTPUT, PIN_PUSH_PULL, PIN_NO_PULL, 0 );
	GpioWrite(&GpsPowerEn,0);




	read_falsh_data(FLASH_USER_ADDR,&g_lorawan_parameter,sizeof(g_lorawan_parameter));
    region = rw_Str2Region((char*)g_lorawan_parameter.region);
	//printf("region = %s\r\n",rw_Region2Str(region));

    //Init master
    modbusMasterInit( &mstatus );

    //Build frame to write single register
	modbusBuildRequest03( &mstatus, 5, 01, 32 );


	DeviceState = DEVICE_STATE_INIT;
	printf("punit soft version: 1.1.3\r\n");



	while(1)
	{
		LoRaWAN_LOOP();
		getchar_loop();
//		HAL_IWDG_Refresh(&hiwdg);

	}
}

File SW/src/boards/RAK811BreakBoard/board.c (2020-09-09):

/*
 / _____)             _              | |
( (____  _____ ____ _| |_ _____  ____| |__
 \____ \| ___ |    (_   _) ___ |/ ___)  _ \
 _____) ) ____| | | || |_| ____( (___| | | |
(______/|_____)_|_|_| \__)_____)\____)_| |_|
    (C)2013 Semtech

Description: Target board general functions implementation

License: Revised BSD License, see LICENSE.TXT file include in the project

Maintainer: Miguel Luis and Gregory Cristian
*/
#include "board.h"

/*!
 * Unique Devices IDs register set ( STM32L1xxx )
 */
#define         ID1                                 ( 0x1FF80050 )
#define         ID2                                 ( 0x1FF80054 )
#define         ID3                                 ( 0x1FF80064 )

/*!
 * LED GPIO pins objects
 */
Gpio_t Led1;
Gpio_t Led2;
Gpio_t REDE;
/*
 * MCU objects
 */
Adc_t Adc;
I2c_t I2c;
Uart_t Uart1;
Uart_t GpsUart;
#if defined( USE_USB_CDC )
Uart_t UartUsb;
#endif

/*!
 * Initializes the unused GPIO to a know status
 */
static void BoardUnusedIoInit( void );

/*!
 * System Clock Configuration
 */
static void SystemClockConfig( void );

/*!
 * Used to measure and calibrate the system wake-up time from STOP mode
 */
static void CalibrateSystemWakeupTime( void );

/*!
 * System Clock Re-Configuration when waking up from STOP mode
 */
static void SystemClockReConfig( void );

/*!
 * Timer used at first boot to calibrate the SystemWakeupTime
 */
static TimerEvent_t CalibrateSystemWakeupTimeTimer;

/*!
 * Flag to indicate if the MCU is Initialized
 */
static bool McuInitialized = false;

/*!
 * Flag to indicate if the SystemWakeupTime is Calibrated
 */
static bool SystemWakeupTimeCalibrated = false;

/*!
 * Callback indicating the end of the system wake-up time calibration
 */
static void OnCalibrateSystemWakeupTimeTimerEvent( void )
{
    SystemWakeupTimeCalibrated = true;
}

/*!
 * Nested interrupt counter.
 *
 * \remark Interrupt should only be fully disabled once the value is 0
 */
static uint8_t IrqNestLevel = 0;

void BoardDisableIrq( void )
{
    __disable_irq( );
    IrqNestLevel++;
}

void BoardEnableIrq( void )
{
    IrqNestLevel--;
    if( IrqNestLevel == 0 )
    {
        __enable_irq( );
    }
}

void BoardInitPeriph( void )
{
    Gpio_t ioPin;

    // Init the GPIO pins
    GpioInit( &ioPin, GPS_POWER_ON_PIN, PIN_OUTPUT, PIN_PUSH_PULL, PIN_NO_PULL, 0 );
    GpioInit( &Led1, LED_1, PIN_OUTPUT, PIN_PUSH_PULL, PIN_NO_PULL, 0 );
    GpioInit( &Led2, LED_2, PIN_OUTPUT, PIN_PUSH_PULL, PIN_NO_PULL, 0 );

    //Init GPS
//    GpsInit( );
	
	//Init LIS3DH
//	LIS3DH_Init( );

    // Switch LED 1, 2 OFF
    GpioWrite( &Led1, 0 );
    GpioWrite( &Led2, 0 );
}

void BoardInitMcu( void )
{
    if( McuInitialized == false )
    {
#if defined( USE_BOOTLOADER )
        // Set the Vector Table base location at 0x3000
        SCB->VTOR = FLASH_BASE | 0x3000;
#endif
        HAL_Init( );

        SystemClockConfig( );
	
		UartMcuInit(&Uart1, UART_1, UART_TX, UART_RX);
		UartMcuConfig(&Uart1, RX_TX, 115200, 
									 UART_8_BIT,
									 UART_1_STOP_BIT,
									 NO_PARITY,
									 NO_FLOW_CTRL);
        RtcInit( );

        BoardUnusedIoInit( );
    }
    else
    {
        SystemClockReConfig( );
    }

    AdcInit( &Adc, BAT_LEVEL_PIN );

    SpiInit( &SX1276.Spi, RADIO_MOSI, RADIO_MISO, RADIO_SCLK, NC );
    SX1276IoInit( );
    GpioInit( &SX1276.Xtal, RADIO_XTAL_EN, PIN_OUTPUT, PIN_PUSH_PULL, PIN_NO_PULL, 1 );
		
    if( McuInitialized == false )
    {
        McuInitialized = true;
        if( GetBoardPowerSource( ) == BATTERY_POWER )
        {
            CalibrateSystemWakeupTime( );
        }
    }
}

void BoardDeInitMcu( void )
{
    //Gpio_t ioPin;

    AdcDeInit( &Adc );

    SpiDeInit( &SX1276.Spi );
    SX1276IoDeInit( );

    //GpioInit( &ioPin, OSC_LSE_IN, PIN_INPUT, PIN_PUSH_PULL, PIN_NO_PULL, 0 );
    //GpioInit( &ioPin, OSC_LSE_OUT, PIN_INPUT, PIN_PUSH_PULL, PIN_NO_PULL, 0 );
	
	GpioWrite( &SX1276.Xtal, 0 );
}

uint32_t BoardGetRandomSeed( void )
{
    return ( ( *( uint32_t* )ID1 ) ^ ( *( uint32_t* )ID2 ) ^ ( *( uint32_t* )ID3 ) );
}

void BoardGetUniqueId( uint8_t *id )
{
    id[7] = ( ( *( uint32_t* )ID1 )+ ( *( uint32_t* )ID3 ) ) >> 24;
    id[6] = ( ( *( uint32_t* )ID1 )+ ( *( uint32_t* )ID3 ) ) >> 16;
    id[5] = ( ( *( uint32_t* )ID1 )+ ( *( uint32_t* )ID3 ) ) >> 8;
    id[4] = ( ( *( uint32_t* )ID1 )+ ( *( uint32_t* )ID3 ) );
    id[3] = ( ( *( uint32_t* )ID2 ) ) >> 24;
    id[2] = ( ( *( uint32_t* )ID2 ) ) >> 16;
    id[1] = ( ( *( uint32_t* )ID2 ) ) >> 8;
    id[0] = ( ( *( uint32_t* )ID2 ) );
}

/*!
 * Factory power supply
 */
#define FACTORY_POWER_SUPPLY                        3300 // mV

/*!
 * VREF calibration value
 */
#define VREFINT_CAL                                 ( *( uint16_t* )0x1FF80078 )

/*!
 * ADC maximum value
 */
#define ADC_MAX_VALUE                               4095
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

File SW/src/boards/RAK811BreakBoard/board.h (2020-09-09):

/*
 / _____)             _              | |
( (____  _____ ____ _| |_ _____  ____| |__
 \____ \| ___ |    (_   _) ___ |/ ___)  _ \
 _____) ) ____| | | || |_| ____( (___| | | |
(______/|_____)_|_|_| \__)_____)\____)_| |_|
    (C)2013 Semtech

Description: Target board general functions implementation

License: Revised BSD License, see LICENSE.TXT file include in the project

Maintainer: Miguel Luis and Gregory Cristian
*/
#ifndef __BOARD_H__
#define __BOARD_H__

#include <stdbool.h>
#include <stdlib.h>
#include <stdio.h>
#include <string.h>
#include <stdint.h>
#include "stm32l1xx.h"
#include "stm32l1xx_hal.h"
#include "utilities.h"
#include "timer.h"
#include "delay.h"
#include "gpio.h"
#include "adc.h"
#include "spi.h"
#include "i2c.h"
#include "uart.h"
#include "radio.h"
#include "sx1276/sx1276.h"
#include "gps.h"
#include "lis3dh.h"
#include "gps-board.h"
#include "rtc-board.h"
#include "sx1276-board.h"
#include "uart-board.h"

#if defined( USE_USB_CDC )
#include "uart-usb-board.h"
#endif

#ifdef LORAWAN_DEBUGGER

#define DPRINTF(...)  printf(__VA_ARGS__) 
#else
#define DPRINTF(...)

#endif

/*!
 * Define indicating if an external IO expander is to be used
 */
//#define BOARD_IOE_EXT

/*!
 * Generic definition
 */
#ifndef SUCCESS
#define SUCCESS                                     1
#endif

#ifndef FAIL
#define FAIL                                        0
#endif

/*!
 * Board IO pins definitions
 */

#define LED_1                                       PA_12
#define LED_2                                       PB_4

/*!
 * Board MCU pins definitions
 */

#define RADIO_RESET                                 PB_13
#define RADIO_XTAL_EN                               PH_1

#define RADIO_MOSI                                  PA_7
#define RADIO_MISO                                  PA_6
#define RADIO_SCLK                                  PA_5
#define RADIO_NSS                                   PB_0

#define RADIO_DIO_0                                 PA_11
#define RADIO_DIO_1                                 PB_1
#define RADIO_DIO_2                                 PA_3
#define RADIO_DIO_3                                 PH_0
#define RADIO_DIO_4                                 PC_13

#define RADIO_RF_CRX_RX                             PB_6  //CRF3
#define RADIO_RF_CBT_HF                             PB_7  //CRF2 HF 
#define RADIO_RF_CTX_PA                             PA_4  //CRF1 PA 

#define OSC_LSE_IN                                  PC_14
#define OSC_LSE_OUT                                 PC_15

#define OSC_HSE_IN                                  PH_0
#define OSC_HSE_OUT                                 PH_1

//#define USB_DM                                      PA_11
//#define USB_DP                                      PA_12

#define I2C_SCL                                     PB_8
#define I2C_SDA                                     PB_9
#define LIS3DH_INT1_PIN		                    	PB_14
#define LIS3DH_INT2_PIN		                    	PB_15

#define UART_TX                                     PA_9
#define UART_RX                                     PA_10

#define GPS_UART        		            		UART_3
#define GPS_POWER_ON_PIN		            		PA_15
#define GPS_UART_TX                                 PB_10
#define GPS_UART_RX                                 PB_11
#define GPS_PPS_PIN                                 PA_0
#define REDE_PIN									PB_2

#define BAT_LEVEL_PIN                               PA_2
#define BAT_LEVEL_CHANNEL                           ADC_CHANNEL_2

#define SWDIO                                       PA_13
#define SWCLK                                       PA_14


/*!
 * LED GPIO pins objects
 */
extern Gpio_t Led1;
extern Gpio_t Led2;
extern Gpio_t REDE;

/*!
 * MCU objects
 */
extern Adc_t Adc;
extern I2c_t I2c;
extern Uart_t Uart1;
extern Uart_t GpsUart;
#if defined( USE_USB_CDC )
extern Uart_t UartUsb;
#endif

/*!
 * Possible power sources
 */
enum BoardPowerSources
{
    USB_POWER = 0,
    BATTERY_POWER,
};

typedef struct{

    uint8_t dev_addr[4];
    uint8_t dev_eui[8];
    uint8_t app_eui[8];
    uint8_t app_key[16];
    uint8_t nwks_key[16];
    uint8_t apps_key[16];
    uint8_t join_mode[2];     // 0x55  0xAA
	uint8_t region[6]; //EU868 US915

}lorawan_config_t;

extern lorawan_config_t g_lorawan_parameter;

/*!
 * \brief Disable interrupts
 *
 * \remark IRQ nesting is managed
 */
void BoardDisableIrq( void );

/*!
 * \brief Enable interrupts
 *
 * \remark IRQ nesting is managed
 */
void BoardEnableIrq( void );

/*!
 * \brief Initializes the target board peripherals.
 */
void BoardInitMcu( void );

/*!
 * \brief Initializes the boards peripherals.
 */
void BoardInitPeriph( void );

/*!
 * \brief De-initializes the target board peripherals to decrease power
 *        consumption.
 */
void BoardDeInitMcu( void );
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

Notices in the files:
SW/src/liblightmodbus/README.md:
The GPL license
